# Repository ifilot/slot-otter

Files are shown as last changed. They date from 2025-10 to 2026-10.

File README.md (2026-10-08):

# Slot-otter





An 8-bit ISA card for accessing FAT16- or FAT32-formatted SD cards under MS-DOS.

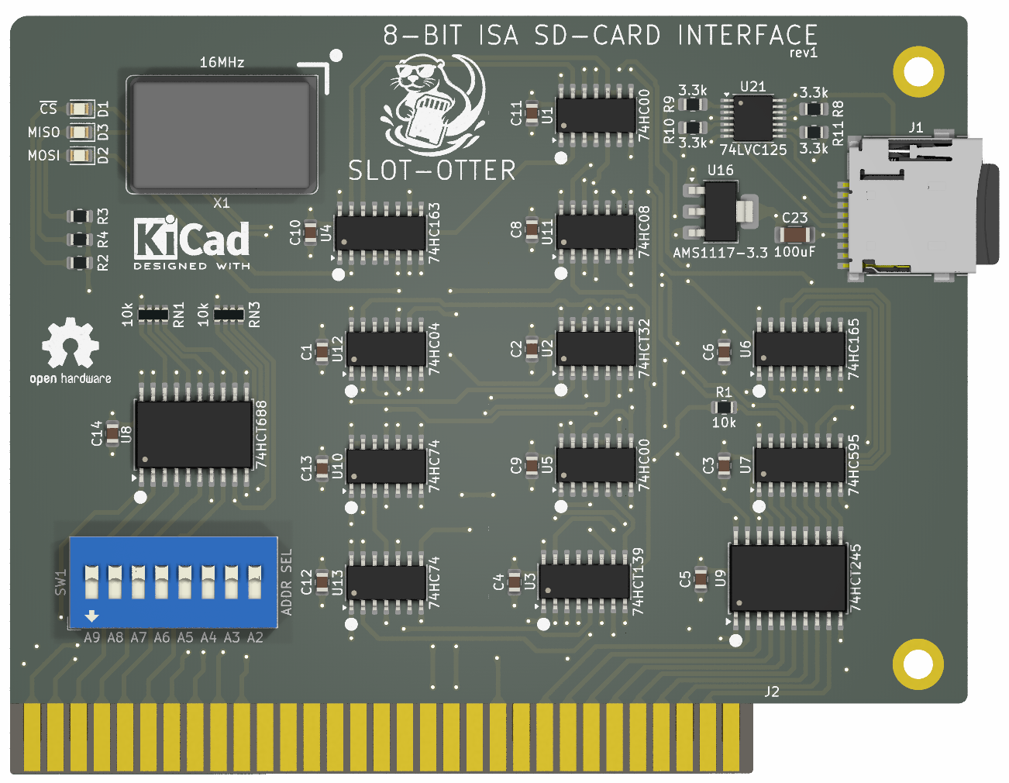
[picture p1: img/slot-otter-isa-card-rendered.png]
Slot-otter ISA card rendered


Slot-otter lets a DOS PC use an SD card as an ordinary drive. Fill the card
with files on a modern computer, insert it into your vintage PC, and copy or
run them from DOS. A working setup has three parts:

- the **Slot-otter card** in a free 8-bit ISA slot;
- the **OTTERSD driver** on the PC's hard drive, loaded at startup;
- an **SD card** with a FAT16 or FAT32 file system.

New users should read [How it works](#how-it-works) and
[Requirements](#requirements), then follow [Getting started](#getting-started)
step by step.

## Contents

- [How it works](#how-it-works)
- [Requirements](#requirements)
- [Getting started](#getting-started)
  - [1. Set the port address](#1-set-the-port-address)
  - [2. Download the driver](#2-download-the-driver)
  - [3. Prepare an SD card](#3-prepare-an-sd-card)
  - [4. Install and load OTTERSD](#4-install-and-load-ottersd)
- [Using the card](#using-the-card)
  - [Changing or removing the SD card](#changing-or-removing-the-sd-card)
  - [Freeing memory for games](#freeing-memory-for-games)
  - [Write checks and read-only mode](#write-checks-and-read-only-mode)
  - [Browsing files with Nightwatch](#browsing-files-with-nightwatch)
- [Performance](#performance)
- [Hardware](#hardware)
- [Legacy Navigator](#legacy-navigator)
- [Development](#development)
- [License](#license)

## How it works

`OTTERSD` is the DOS driver for Slot-otter. It is usually started from
`AUTOEXEC.BAT`. It talks to the card over the ISA bus, reads the FAT16 or FAT32
file system on the SD card, and gives the card an ordinary drive letter such
as `S:`. From then on, DIR, COPY, XCOPY, games and other DOS programs use the
card like any other drive and never need to know it is an SD card.

A driver is needed because, on its own, MS-DOS can only use the storage the
PC's BIOS already supports, which means floppy drives and hard disks. Any
other storage device needs a small program that stays in memory and turns DOS
requests such as "open this file" or "list this directory" into commands the
hardware understands. CD-ROM drives are the familiar example. Before a `D:`
drive appears, `CONFIG.SYS` has to load the manufacturer's CD-ROM driver and
`AUTOEXEC.BAT` has to run `MSCDEX`. `OTTERSD` does both of those jobs in a single
program.

## Requirements

Check these before you start. The driver refuses cards or file systems it
cannot handle safely.

- **PC:** an 8088/8086 or later processor and a free 8-bit ISA slot.
- **DOS:** MS-DOS or PC-DOS 3.1 through 6.x.
- **Memory:** about 42 KiB of conventional memory while the driver is loaded.
  No EMS or XMS is needed.
- **SD card:** SDHC or SDXC, at least 501 MiB. Older SDSC cards (2 GB and
  smaller) are not supported.
- **File system:** FAT16 or FAT32 with standard 512-byte sectors on an MBR
  partition. FAT12, exFAT, GPT and extended partitions are not supported.
- **File names:** the usual DOS limit of eight characters for the name and
  three for the extension, such as `DUNE2.EXE`.

## Getting started

Setting up Slot-otter for the first time takes four steps. The first is done
on the card before it goes into the PC, the third on a modern computer, and
the rest under DOS.

1. Set the card's port address and install it in the PC.
2. Download the driver and copy it to the DOS hard drive.
3. Write an empty FAT16 or FAT32 image to an SD card and add your files.
4. Install and load OTTERSD.

### 1. Set the port address

The PC talks to expansion cards through I/O ports, small numbered addresses
that each card listens on. Slot-otter occupies four consecutive ports. The
driver needs to know where they start, and no other card in the PC may use
the same ones.

The base address is set with the 8-position DIP switch labelled **ADDR SEL**
(SW1). Each switch stands for one value. Switches that are ON add their
values together to give the base address; switches that are OFF add nothing.

| Switch | 1 | 2 | 3 | 4 | 5 | 6 | 7 | 8 |
| --- | --- | --- | --- | --- | --- | --- | --- | --- |
| Value (hex) | 200 | 100 | 80 | 40 | 20 | 10 | 8 | 4 |
| **330h** (default) | ON | ON | OFF | OFF | ON | ON | OFF | OFF |
| **300h** | ON | ON | OFF | OFF | OFF | OFF | OFF | OFF |

For example, 330h = 200h + 100h + 20h + 10h, so switches 1, 2, 5 and 6 are ON.
The examples in this README and the driver documentation use 330h. Choose any
free address from 100h to 3FCh. Sound cards often use 330h for their MIDI
port, so pick another address, such as 300h, if your PC has one. Whatever you
choose, pass the same value to the driver with `/PORT:` in
[step 4](#4-install-and-load-ottersd).

With the PC switched off, insert the card into a free 8-bit ISA slot.

### 2. Download the driver

The driver is distributed as a ZIP for copying with a modern PC, as a bare
executable, and as floppy images for PCs that only have a floppy drive. Get
the [latest release](https://github.com/ifilot/slot-otter/releases/latest):

- [OTTERSD-DOS.zip](https://github.com/ifilot/slot-otter/releases/latest/download/OTTERSD-DOS.zip): driver, instructions and license.
- [OTTERSD.EXE](https://github.com/ifilot/slot-otter/releases/latest/download/OTTERSD.EXE): driver executable.
- [floppy_360k.img](https://github.com/ifilot/slot-otter/releases/latest/download/floppy_360k.img): 360 KiB, 5.25-inch DD.
- [floppy_720k.img](https://github.com/ifilot/slot-otter/releases/latest/download/floppy_720k.img): 720 KiB, 3.5-inch DD.
- [floppy_1440k.img](https://github.com/ifilot/slot-otter/releases/latest/download/floppy_1440k.img): 1.44 MiB, 3.5-inch HD.
- [SHA256.TXT](https://github.com/ifilot/slot-otter/releases/latest/download/SHA256.TXT): checksums for checking that downloads are intact.

Floppies contain only the driver, user instructions, configuration example
and license. They contain no testing utilities and are not boot disks.
Write them to physical floppies or use GoTek,
[BitstreamBeaver](https://github.com/ifilot/bitstream-beaver) or FlashFloppy.

### 3. Prepare an SD card

The easiest way to get a card in the right format is to write one of the
ready-made images to it on a modern PC. Both images contain an **empty,
formatted partition** with no files or folders. After writing one, copy your
files onto the card with the same PC.

**Recommended: [500 MiB FAT16, 16 KiB clusters](https://github.com/ifilot/slot-otter/releases/latest/download/OTTERSD-FAT16-500MiB.zip).**
This gives a useful balance of storage space and write speed. A cluster is
the unit of space the card assigns to a file. Larger clusters mean less
bookkeeping when growing a file, although small files take up more space.

An alternative [500 MiB FAT32 image with 4 KiB clusters](https://github.com/ifilot/slot-otter/releases/latest/download/OTTERSD-FAT32-500MiB.zip)
is also available.

Extract the ZIP and write its IMG to the **entire card**. This replaces existing
partitions and files: back up first and select the correct device. Do not copy
the IMG as a file or reformat the card afterwards. The image occupies 501 MiB,
including a small area before the 500 MiB partition. On a larger card, the
remaining space is unused by this image. These images hold your files; they
do not boot DOS.

A card that is already formatted FAT16 or FAT32 and meets the
[requirements](#requirements) can also be used without writing an image.

### 4. Install and load OTTERSD

The driver is copied to the hard drive and started like any other DOS program.
It must not be loaded from the SD drive it provides.

Copy OTTERSD.EXE to a directory on your DOS hard drive, such as `C:\OTTERSD`.
Choose an unused drive letter; this example uses `S:`. Add `LASTDRIVE=S` to
CONFIG.SYS (or keep an existing value of S or later), then reboot, insert the
SD card and load:

```dos
C:\OTTERSD\OTTERSD /DRIVE:S /PORT:330 /RW
```

`/PORT:330` must match the DIP-switch setting from
[step 1](#1-set-the-port-address). `/RW` enables writing with read-back checks.
Omit it or use `/RO` for read-only access. Once the driver reports that the
card is mounted, you can use commands such as `DIR S:\`.

Add the loading command to AUTOEXEC.BAT if you want it to run at startup.
Run OTTERSD as a program; do not add it as a `DEVICE=` line in CONFIG.SYS.
See the [installation guide](driver/docs/INSTALLATION.md) for the full setup
and available options.

## Using the card

Once loaded, the SD drive behaves like any other DOS drive. A few things
differ from a fixed hard disk, mainly because the card can be removed and the
driver can be unloaded.

### Changing or removing the SD card

**Always unmount before removing a card, and mount again after inserting one.**
Treat this like safely ejecting a card on your modern PC. DOS programs and
the driver can keep file data and information about the card in memory.
Removing or swapping a mounted card can lose changes or cause the driver
to use information belonging to the previous card, risking file corruption.

1. Finish copying and close any programs using the SD card. Return to a
   drive other than the SD card, such as `C:`.
2. Run `C:\OTTERSD\OTTERSD /UNMOUNT`. **Wait for it to succeed before
   removing the card.** If it reports an error, leave the card inserted
   and resolve the error first.
3. Remove the card and insert the card you want to use.
4. Run `C:\OTTERSD\OTTERSD /MOUNT` and wait for it to succeed before
   accessing the SD drive again.

Follow these steps even when reinserting the same card, especially after
changing its contents on another computer. Unmounting leaves the driver
loaded, so you do not need to reboot to change cards.

### Freeing memory for games

Some games need every kilobyte of conventional memory. The driver can be
removed from memory without rebooting: close programs using the SD card,
switch to your hard drive and run `C:\OTTERSD\OTTERSD /UNLOAD`. Run the
loading command again to bring the SD drive back.

### Write checks and read-only mode

With `/RW`, every block written to the card is read back and checked before
the write is reported as successful. With `/RO`, or without either option,
the card is mounted read-only and nothing on it can be changed. The access
mode is fixed when the driver is loaded; reboot to change it.

### Browsing files with Nightwatch

For browsing and copying files, we recommend
[Nightwatch](https://github.com/ifilot/nightwatch) together with OTTERSD.
Nightwatch is a separate project and is not bundled in these downloads.

## Performance

File-copy tests on an **80286 running at 20 MHz** gave these results:

| Direction | FAT16 card | FAT32 card |
| --- | --- | --- |
| To the SD card | 15 KiB/s | 10 KiB/s |
| From the SD card | 38 KiB/s | 38 KiB/s |

These are measured file-transfer speeds, not guaranteed speeds for every
system or card. FAT16 was faster when writing in these tests; reading was
equally fast with both formats. Speeds also depend on the CPU, the ISA bus
and the disk being copied to or from.

## Hardware

The KiCad design files for the card are in [pcb/release](pcb/release),
including the schematic as a [PDF](pcb/release/isa-sdcard.pdf) and the BOM
and placement files for assembly. The card is built from standard 74-series
logic. A 74HCT688 compares address lines A2 to A9 with the DIP-switch setting
described in [Set the port address](#1-set-the-port-address).

## Legacy Navigator

OTTERNAV remains available for users of the older software. It accesses the
card directly, without loading OTTERSD. Its source is under [src](src/README.MD), with a separate
[OTTERNAV.EXE download](https://github.com/ifilot/slot-otter/releases/latest/download/OTTERNAV.EXE).
It is not included on the OTTERSD floppies. Unmount OTTERSD before using Navigator
on the same card.

## Development

Standalone driver source, build scripts and regression tests live under
[driver](driver/README.md), together with the technical documentation.
Turbo C 2.0 and TASM 2 build the binaries.
[DOSBox-VirtIsa](https://github.com/ifilot/dosbox-virtisa) models the ISA interface;
real DOS kernels and hardware provide additional validation. Developer hardware
kits and test images are separate from public downloads. Disk images,
release packages and build outputs are generated by the tools and GitHub
Actions; they are not stored in the source repository.

## License

Slot-otter is released under the
[GNU General Public License v3.0](https://www.gnu.org/licenses/gpl-3.0).

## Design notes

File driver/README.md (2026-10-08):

# OTTERSD driver

This directory contains the source, build scripts and tests for `OTTERSD.EXE`,
the DOS driver for the Slot-otter card, and `HWRT.EXE`, its developer
hardware tester. It is self-contained: nothing here depends on the
legacy Navigator in `../src`.

This document is for developers. End users should follow the
[installation guide](docs/INSTALLATION.md), which is also shipped as
`README.TXT` in the public downloads.

## Contents

- [Overview](#overview)
- [Command-line reference](#command-line-reference)
- [Platform and scope](#platform-and-scope)
- [Design](#design)
- [Source layout](#source-layout)
- [Building and testing](#building-and-testing)
- [Releasing](#releasing)

## Overview

OTTERSD is a TSR filesystem redirector. It hooks the DOS network-redirector
interface (INT 2Fh), so it is started as an ordinary program, for example from
AUTOEXEC.BAT, rather than loaded with `DEVICE=` in CONFIG.SYS. Once installed,
it reads the FAT16 or FAT32 volume on the SD card and serves DOS file requests
for the chosen drive letter. A single executable handles both file systems,
read-only and verified read/write access.

CONFIG.SYS needs a LASTDRIVE at or beyond the chosen letter. The tested
configuration is:

```dos
LASTDRIVE=S
FILES=40
BUFFERS=10
```

## Command-line reference

Install from a local disk, never from the SD drive itself:

```dos
OTTERSD /DRIVE:S /PORT:330 /RW
```

| Option | Meaning |
| --- | --- |
| `/DRIVE:x` | Drive letter to provide (C to Z). Required at installation. |
| `/PORT:hhh` | Card base port in hexadecimal, matching the DIP switch. Default 330. |
| `/RO` | Read-only access. This is the default. |
| `/RW` | Read/write access with read-back verification of every sector. |
| `/NOVERIFY` | With `/RW`: skip the read-back. See [Write verification](#write-verification). |
| `/SKIPFATCHECK` | With `/RW`: faster mount. See [Mounting](#mounting). |
| `/FAT16`, `/FAT32` | Accept only that file system. Without either, it is detected automatically. |

The access mode and options are fixed at installation; reboot or `/UNLOAD`
to change them. A second installation is rejected. If no usable card is
present, the driver stays loaded with the drive offline.

Control commands operate on the installed driver:

| Command | Effect |
| --- | --- |
| `OTTERSD /STATUS` | Report version, mode, policies and the last SD diagnostic. |
| `OTTERSD /UNMOUNT` | Commit and check the FAT copies, mark the volume clean and take the drive offline. Required before removing the card, rebooting or using Navigator. |
| `OTTERSD /MOUNT` | Bring the drive online again after inserting a card. |
| `OTTERSD /UNLOAD` | Remove the driver completely and free its memory. |

`/UNMOUNT` and `/UNLOAD` refuse to run while files on the SD drive are open.
`/UNLOAD` must also be run from another drive, and it refuses if a TSR loaded
later has hooked INT 2Fh after OTTERSD, if DOS memory ownership is not as
expected, or if a commit fails. A failed mount or transport operation leaves
the drive offline with the TSR still loaded. Handles and searches opened
before that point cannot resume against a different card.

## Platform and scope

- **CPU:** 8088/8086 or later. No 286 instructions, EMS, XMS, DMA or IRQ line are used.
- **DOS:** MS/PC-DOS 3.1 through 6.x. DOS 5 and 6.22 with 1 MiB of emulated RAM
  are the qualification kernels. DOS 3/4 and a physical 5150/8088 are not yet
  tested; a 286 with 1 MiB is the current hardware target.
- **Media:** SDHC/SDXC with 512-byte sectors; FAT16 or FAT32 in the first
  primary MBR partition, or as a superfloppy.
- **Memory:** 42,896 bytes of conventional memory including the PSP, in either
  access mode. Validation and packaging fail above 45,000 bytes. Resources include a
  2,048-byte private stack, 16 open-file slots and 32 search cursors. DOS
  FILES and process limits also apply.

File names are DOS 8.3 names or the 8.3 aliases of existing long names.
Supported operations include creating, overwriting, appending, truncating
and extending files; deleting files; attributes and timestamps; creating and
removing directories; and moving across directories. Handle sharing,
duplicate handles and region locks are implemented. Standard FCB wildcard
deletion is tested; FCB record I/O and abort handling are not.

Not supported: GPT, extended partitions, SDSC cards, FAT12, exFAT, creating
long file names, and general DOS network-server functions.

## Design

### Write verification

By default, every 512-byte sector written goes through these checks: a CRC,
the card's accepted response, bounded busy and status waits, a CRC-checked
read-back, and an exact comparison with the intended data. The intended data
is held in a frozen copy for the duration of the write. A failed sector is
tried at most three times in total, and only after the card's identity and
usable reads have been re-established. If the failure cannot be resolved, the
session is poisoned and no further writes are accepted.

`/NOVERIFY` drops only the read-back and comparison. CRC, response, busy,
CMD13 status, identity and recovery checks remain. It can therefore
acknowledge data the card stored incorrectly, and must be chosen explicitly
at installation. The installer, `/STATUS` and HWRT report the active policy.
The diagnostic `verified` counter counts completed sector writes in both modes.

Writes are synchronous; there is no write-back cache. Verified sector writes
do not make multi-sector FAT updates transactional. Closing a file finishes
its data and directory writes but leaves the volume marked dirty, to avoid
comparing both complete FATs on every close. An explicit DOS commit, a global
flush and `/UNMOUNT` compare the FAT copies before marking the volume clean.
A volume left dirty by an interrupted session is refused at the next mount and
needs checking on another computer; the driver never clears the flag silently.

### Mounting

A full mount checks the geometry, capacity, backup boot sector, FAT flags,
FSInfo signatures and that all FAT copies match. It does not scan for
allocation errors or cross-linked files.

`/SKIPFATCHECK` skips the complete FAT comparison at mount and compares only
the first FAT sector. All other mount checks, the comparisons made before FAT
changes and the full commit checks remain. It requires `/RW`; `/RO` never
performs the full comparison.

### Caching and card changes

Reads use separate caches: one payload sector, four FAT sectors and two
directory sectors. Under `/RW`, each open handle also keeps its position in
the cluster chain, so sequential reads need not walk the chain from the start.
Every cached FAT access, including a cache hit, rechecks the card's identity.
Before any write, all retained positions are invalidated and any cached copy
of the sector being written is discarded. A write starts its own validation
from freshly read data rather than from cached results. Removing or replacing
the card invalidates the mounted file system. Cards must be unmounted before
raw-sector tools or Navigator change them.

### Allocation

Newly allocated clusters for regular files receive the incoming data directly,
without being zeroed first. File reads stop at the end of the file, so stale
bytes beyond it are never visible. Gaps and explicit extensions are filled
with zeros, and new directory clusters are cleared before they are linked.

### Disk-space reporting

The DOS free-space call uses 16-bit counts. To report large volumes, the
driver presents larger logical allocation units than the physical clusters,
up to 32 KiB, and rounds total and free counts down. The physical geometry is
unchanged. Volumes above about 2 GiB still exceed what the call can report.

## Source layout

| File | Responsibility |
| --- | --- |
| INSTALL.C / INSTALL.H | Installation and control commands; discarded after loading |
| BOOT.C / CRT.C | Retained bootstrap and CRT/far call gates |
| ENTRY.ASM | 8086 interrupt bridge, private stack and resident boundary |
| REDIR.C / RWOPS.C / RWDIR.C | DOS redirector, handles, locks and write callbacks |
| FAT32.C / RWFS.C / RWFS.H | FAT16/FAT32 reading, writing and directory operations |
| SDRW.C / RWSD.H | Card identity, recovery and verified sector transport; version number |
| FASTIO.ASM | 8086 far memory copy |
| PORTBODY.H | Shared, exhaustively tested option parser |
| HWRT.C / TESTCHLD.C | Hardware tester, including its self-exec child mode |
| installer_segments.py / tests/layout.py | Checks that installer segments are discarded and the startup reserve fits |

| Directory | Contents |
| --- | --- |
| `docs/` | [Installation guide](docs/INSTALLATION.md), [hardware test manual](docs/MANUAL.md), developer image notes ([FAT16](docs/FAT16_IMAGE.md), [FAT32](docs/LARGE_IMAGE.md)), [source conventions](docs/CODING.md) and [DOS ABI notes](docs/DOSREF.md) |
| `tests/` | Host, mutation, native DOS and XCOPY tests; see [tests/README.md](tests/README.md). `tests/reference/` holds earlier protocol code used only as test input; `tests/emulation/` holds the SD card model and emulator adapters. |
| `logs/` | Physical-card logs: `logs/historical/` for earlier runs, `logs/<card-name>/` for new ones |
| `dist/` | Generated build, kit and release output. Ignored by Git. |

## Building and testing

### Requirements

Turbo C 2.0 and TASM 2 are supplied separately, in `../buildenv` or the
directory named by `TOOLCHAIN_DIR`. `DOSBOX_BIN` selects the DOSBox used to
run the compiler. Python 3, GCC/gcov, mtools and dosfstools are needed for the
host tests and packaging.

### Build and validate

```sh
bash driver/build.sh /tmp/otter-build
python3 driver/validate.py --output /tmp/otter-check
python3 driver/validate.py --full --output driver/dist \
  --dosbox /path/to/dosbox-with-isa-model \
  --boot-image /path/to/dos5.img --boot-image /path/to/dos622.img
```

`build.sh` builds both programs. `validate.py` runs the host regression,
coverage and mutation tests, builds both programs and creates a candidate
developer kit.

`--full` also boots real DOS in an emulator with the
[DOSBox-VirtIsa](https://github.com/ifilot/dosbox-virtisa) ISA model. It runs:
- read-only, command-line, EXEC and card-swap tests;
- write-fault profiles and tester guards;
- XCOPY from a BIOS hard disk at two cluster sizes and with each write policy;
- stress, memory and reboot tests on the final image, with independent
  content comparison and fsck.

These tests need `XCOPY.EX_` in each boot image and `EXPAND.EXE` in one of
them, or in `--xcopy-expand-media`. Boot images, compiler images, XCOPY and
the emulator are not redistributed. Results, gate logs and
`EVIDENCE/QUALIFICATION.JSON` are written to the output directory.

Emulation does not qualify physical hardware.

### Testing on a real card

Validation produces developer kits with HWRT and test fixtures:
`dist/OTTERSD.IMG` (small FAT32 stress image) with `dist/OTTERSD.ZIP`, plus
500 MiB images in `dist/FAT16/` and `dist/500M/`. Follow the
[hardware test manual](docs/MANUAL.md) separately for each card. HWRT records
the card's CID, capacity, versions, source identifier, timings and
diagnostics. Save each card's logs under `logs/<card-name>/`. Results from an
earlier build do not carry over to a new one.

## Releasing

`release.py` builds the public downloads from a qualified `OTTERSD.EXE`:

```sh
python3 driver/release.py --driver /path/to/OTTERSD.EXE \
  --output /path/to/new-public-output
```

It produces:
- the DOS ZIP;
- 360 KiB, 720 KiB and 1.44 MiB installation floppies;
- empty 500 MiB FAT16 and FAT32 SD images, with FAT16 at 16 KiB clusters recommended;
- `SHA256.TXT`.

The ZIP and floppies contain only `OTTERSD.EXE`, `README.TXT` (from
[INSTALLATION.md](docs/INSTALLATION.md)), a CONFIG.SYS example and the
license. They include no HWRT, fixtures or test markers. The script never uses
the developer fixture builders. It refuses an existing output directory and
checks each floppy's file list, the SD geometry, FAT copies, root contents,
backup boot sector, FSInfo and fsck results. Local output can be placed in
`dist/RELEASE/`.

GitHub Actions runs the host and mutation tests, builds the binaries and
uploads only `release.py`'s output. A tagged release requires the tag to be
`v` followed by the version in RWSD.H. OTTERNAV is built separately and
attached as an optional legacy download.

RWSD.H defines the displayed version and a 16-bit resident version ID: the
major version in the high byte, and minor and patch in the two low nibbles.
HWRT refuses to work with a driver of a different version.

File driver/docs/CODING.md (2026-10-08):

# Resident source conventions

The DOS sources target Turbo C 2.0's C89 subset and TASM's `.8086` instruction
set. Keep declarations at block starts, use `/* ... */` comments in C and `;`
comments in assembly, and retain explicit `far` pointers at DOS memory and
transfer boundaries. Modern Python and the host card model are test tools;
they need not imitate a 1980s compiler.

Use the existing U8/U16/U32 types when width is part of a disk format or DOS
ABI. DOS `int` is 16 bits. A far pointer's offset is also 16 bits; ordinary
pointer addition is insufficient for a transfer crossing offset FFFFh.
Keep unsigned arithmetic explicit where overflow, sector bounds or time
counter wrap is intentional.

Comments should explain contracts, ownership, ordering and unusual constraints.
Document which error survives a failure and which state is invalidated. Avoid
restating obvious assignments or turning measured evidence into a guarantee.
DOSREF.md records DOS structure offsets and the private diagnostic interface;
RWSD.H and RWFS.H describe the transport and filesystem contracts.

Resident callbacks must not call DOS, allocate memory, or print diagnostics.
The interrupt bridge provides a static stack and prevents nested use of shared
scratch. Installation code may use DOS before becoming resident. The linker
boundary includes all resident code/data and the private stack, and releases
the startup stack/heap and explicit far installer tail after installation.
BOOT gates are the only external far targets permitted in installer assembly;
local far frames must also be verified before linking. PORTBODY.H shares the
parser implementation between retained test utilities and the far installer.

Verified sector writes do not make FAT operations atomic. Mount preflight is
not a complete consistency scan. Any claim about recovery, memory use, or a
DOS API must distinguish host tests, actual booted DOS and physical hardware.

For a comments-only pass, retain a pre-edit build and compare rebuilt EXE files
byte for byte. Run the regression suite as well. Formatting changes are kept
small so an invariant explanation remains easy to review separately from a
behavior change.

FASTIO.ASM uses a near small-model C call for normalized far memory copying.
Its source and destination must be normalized before each <=512-byte chunk;
neither offset may wrap. The helper preserves BX/SI/DI/BP/DS/ES, clears DF and
leaves interrupts enabled. Native tests check odd tails, source preservation,
segments and register contracts with deliberately broken assembly variants.

The SD transport in SDRW.C is the complete 0.6 C implementation restored after
a physical regression in 0.7. Its OUT plus settling/sample reads must not be
compressed into assembly without an elapsed-time contract and physical proof.
An emulator that counts accesses cannot establish electrical settling time.
The C CRC is tested against independent host and native bitwise oracles.

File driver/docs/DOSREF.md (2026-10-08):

# Writable redirector ABI references

The original [Ralf Brown Interrupt List, release 61](https://www.cs.cmu.edu/~ralf/files.html)
is the authority for the undocumented DOS interfaces used here (INTERRUP.K,
tables 02606, 01687, 01690, 01641/01642/01643). Do not substitute DOSBox's
built-in DOS behavior for actual kernel validation.

- DOS 3 locks pass position in CX:DX and length in SI plus a stack word.
  DOS 4–6 use BL to distinguish lock/unlock and DS:DX to an eight-byte
  position/length record; CX is one. Unlock must match the original range.
- Create uses stack attributes and a create-new flag. Extended open instead
  uses the SDA action, mode, and attributes; DOS 5/6 have documented stack
  attribute and returned-action bugs. Callback action results remain correct.
- Rename's second canonical pathname is 128 bytes after the first pathname
  buffer. These buffers have different sizes from this driver's path limit.
- DOS owns SFT reference counts on open; the redirector decrements them on
  close. Commit flushes without decrementing them.
- File time updates arrive through the SFT. File creation dates use the SDA
  date and time derives from the BIOS tick count without reentering DOS.
- Ordinary DOS UNLINK rejects wildcards before reaching the redirector.
  FCB deletion (INT 21h/AH=13h) and COMMAND.COM DEL pass under booted DOS 5
  and 6.22, including a directory grown across cluster boundaries. The optional
  `/SERVER` probe using canonicalized INT 21h/AX=5D00h still returns error 3
  without a new redirector error; that experiment is not a validated path.

SFT offsets used for DOS 3.1-6.x (byte offsets, little endian):

| Offset | Field | Ownership |
|---|---|---|
| 0 | reference count, WORD | DOS initializes; redirector decrements on close |
| 2 | open mode, WORD | redirector stores validated DOS mode |
| 4 | attributes, BYTE | refreshed from directory metadata |
| 5 | device/network flags, WORD | remote drive and inheritance flags |
| 7 | device/DPB or redirector pointer, DWORD | unused here; initialized to zero |
| 11 | starting cluster, WORD | unused for remote FAT32; full cluster lives in driver state |
| 13, 15 | FAT time/date, WORDs | preserve pending DOS handle-time updates |
| 17 | file size, DWORD | synchronize all open SFTs when size changes |
| 21 | file position, DWORD | individual SFT position; duplicates share it |
| 25-31 | cluster/position fields | initialized; traversal lives in driver state |
| 32-42 | short filename | eleven-byte padded alias |
| 43 onward | sharing/process linkage | preserve DOS-owned fields on open |

The writable build's private INT 2Fh/AX=D74Fh query is for the test program and
installer. Discovery without the control signature returns AX=4F54h,
BX=524Fh, CX=zero-based drive, DX=online, SI=open SFT slots, DI=ISA base port.
BP=3 identifies the enhanced build; BP=2 is the older read-only build.
Discovery checks media presence and can take the driver offline.

Controls require BX=4F54h and DX=524Fh. CF indicates failure with a DOS error
in AX; otherwise AX is zero except for selectors with explicit AX results:

| SI | Operation | Successful results |
|---|---|---|
| 1 | unmount after flushing | fails while any resident file slot is open |
| 2 | initialize and remount in installed mode | also requires zero file slots |
| 4 | copy transport diagnostics | ES:DI writable buffer, CX at least 40; CX=40 |
| 5 | installed mode | BX=write enabled, CX=3 total sector attempts, DX=online, DI=post-write readback enabled |
| 6 | last callback failure | AX=11xx function, BX=DOS error before kernel mapping |
| 7 | observed private stack use | AX=used, BX=untouched prefix, CX=2048 |

Selector 4 rejects a buffer crossing the 16-bit offset boundary. Its fixed
40-byte layout and stage/counter meanings are in RWSD.H. Unmount preserves
transport diagnostics; remount clears them even when its initialization fails.
The last callback failure is sticky, so it can describe an earlier operation.
Stack scanning measures observed use of the A5 pattern, including IRQs during
callbacks; it does not prove the maximum possible stack demand.

Process/FCB termination callbacks 111Dh and 1122h currently chain. RBIL describes
the sharing PSP at SDA 1Ah (DOS 3) or 1Ch (DOS 4-6), distinct from the current
PSP at 10h. Normal DOS process exit is tested with seventeen child runs leaving
six handle-based files and one region lock unclosed. DOS close callbacks release
all resident slots and locks. Abnormal abort and FCB record-I/O handle lifetime
remain unqualified; do not infer them from the normal-exit result.

See the specific [write callback](https://fd.lod.bz/rbil/interrup/network/2f1109.html),
[rename callback](https://fd.lod.bz/rbil/interrup/network/2f1111.html), and
[extended open callback](https://fd.lod.bz/rbil/interrup/network/2f112e.html).

## Consolidated identity query (action 8)

The private D74Fh/OT/RO multiplex control uses SI=8, CX >=32 and ES:DI pointing
to a 32-byte DriverInfo. Far offsets at FFE0h and above are rejected. CF clear returns
CX=32. Fields are last LBA (U32), CID (16 bytes), version (U16,000Bh), resident
bytes, SD ticks, filesystem ticks, flags and ABI (U16,1). Flags: bit0 cached
identity valid, bit1 installed writable mode, bit2 online, bit3 post-write readback disabled. CID is zero when
invalid; capacity is meaningful only with valid identity. This cached query
performs no SD I/O and does not freshly authenticate a removed card.
Mount tick fields are U16 BIOS low-word deltas for short operations; midnight
reset or unusually long mounts can distort them. The older 40-byte action4
diagnostic layout is unchanged.

The action4 `verified` counter retains its completed-sector-call ABI meaning.
With flag bit3 set it does not certify sector readback. /NOVERIFY is fixed at
installation and does not disable command/data CRC or recovery reads.

## DOS disk-space geometry

[INT 2F/110Ch](https://fd.lod.bz/rbil/interrup/network/2f110c.html) returns
AL sectors per allocation unit, AH media ID, BX total units, CX bytes per
sector and DX available units. Total/free counts are only 16 bits. Version
0.9 doubles the reported allocation unit and halves both counts until the
total fits, keeping synthesized units at most 32 KiB. Counts round down, so
the result loses less than one logical unit when the volume is representable.
The FAT32 BPB, physical cluster size and allocator do not change. A 500 MiB
volume with 4 KiB physical clusters is reported using 8 KiB logical units.
Read-only mode reports total capacity but zero writable free units. The
legacy interface still saturates above approximately 2 GiB at that unit-size
ceiling; this is not an extended FAT32 disk-space API. Pre-existing 64 KiB
physical clusters retain their previous unit size rather than wrapping AL.

### Unload ABI (OTTERSD 0.10)

Private INT 2F AX=D74Fh, BX=4F54h, DX=524Fh, SI=9 returns CF clear,
AX=resident PSP, BX:CX=own vector offset:segment, DX:DI=previous vector
offset:segment, SI=000Ah. This query does not flush or mutate the drive.
SI=10 prepares detachment: verify the topmost INT 2F vector, reject open files
or a poisoned/lost dirty session, flush writable online media, take it offline, restore
all 51h (DOS 3) or 58h (DOS 4+) saved CDS bytes. CF/AX reports failure; commit
failure leaves the CDS and hook installed. The transient caller must verify
the current drive and DOS MCB ownership before SI=10, then restore the saved
vector and free the PSP allocation with INT 21/AH=49 only after returning.
Never call DOS or free the allocation on the resident interrupt stack. No
third-party hook may be bypassed. These operations are version-matched and
intended for the shipped /UNLOAD command, not a generic TSR chain editor.

### Fast-mount policy in 0.11

DriverInfo ABI 1 remains 32 bytes. Flags bit 4 (0010h) records the installed
/SKIPFATCHECK policy; other flag meanings are unchanged. Private unload query
SI=9 returns version SI=000Bh for this release. /SKIPFATCHECK skips only the
full mount scan. FAT sector zero is compared at mount and before clean/dirty
flag publication, modified FAT sectors remain compared, and rw_flush still
compares all mirrors for a dirty session. No policy control changes an already
resident instance. Read-only mounting does not perform the full scan.

### Dual-format status flags (OTTERSD 0.13)

DriverInfo ABI 1 remains 32 bytes. Flags 0020h identify a mounted FAT16 volume;
with mounted flag 0004h set and 0020h clear, the volume is FAT32. Offline volumes
have no reported type. Flags 0040h and 0080h record `/FAT16` and `/FAT32`
restrictions respectively; both clear means automatic detection. Restrictions
persist across unmounts, removals, and explicit remounts. No on-disk format
conversion occurs. The internal ROOT16 sentinel is FFFFFFFFh and never a data
cluster. FAT16 reserved/EOF entries normalize into the existing internal FAT32
marker range; writes serialize only the original two-byte FAT16 entries.

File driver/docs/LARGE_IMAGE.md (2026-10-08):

# Developer 500 MiB FAT32 SD image

For the empty END-USER image, use `dist/RELEASE/OTTERSD-FAT32-500MiB.zip`
and [INSTALLATION.md](INSTALLATION.md). The fixture below is for developers
and is not included in the public release.

OTTER500.IMG contains one 500 MiB FAT32 partition at a 1 MiB offset in an MBR
disk image. The entire image is 501 MiB. It uses 512-byte sectors, 4 KiB
clusters (eight sectors), two FAT copies, FSInfo and a backup boot sector.
The data area begins at 2 MiB, so both the partition and data are 1 MiB aligned.
It is a data disk, not a bootable DOS disk. Extra capacity on a larger card
remains outside this partition.

The previous small image intentionally used 512-byte clusters to exercise
allocation heavily. A 400 KiB file needs 100 clusters with this image instead
of 800. This reduces FAT allocation and chain traversal work. Sector writes
still transfer 512 bytes, with CRC and default readback verification. Larger
clusters do not remove that cost. Small files can waste up to 4095 bytes each.
Mount and unmount compare complete FAT copies; their cost can increase with
this larger volume. Measure copying separately from mount/unmount.

Eight KiB clusters would put a 500 MiB volume below the FAT32 minimum of
65525 data clusters. Four KiB keeps this image unambiguously FAT32. Changing
the sector size is a different operation and is not supported by this driver.
OTTERSD 1.0.0 reports 8 KiB logical allocation units to DOS on this volume,
scaling total/free counts to fit the legacy 16-bit interface. The physical
clusters stay 4 KiB. DIR should report about 499 MiB free initially, allowing
for the FAT/reserved area and supplied files. Reported free space rounds down
by less than 8 KiB. Read-only mode reports zero writable free space.
The cluster-count rule is specified in Microsoft's FAT specification:
https://www.cs.fsu.edu/~cop4610t/assignments/project3/spec/fatspec.pdf (pages 14-15).

## First hardware run

1. Back up the spare card. Flash OTTER500.IMG to the entire card with your
   usual image-writing tool. This replaces the partition table and files.
   Do not copy the image as a file or reformat the partition afterwards.
2. Boot DOS with the driver absent. Use Navigator to copy every file in KIT
   to a local writable directory, such as C:\OTTERSD. Exit Navigator.
3. Ensure CONFIG.SYS contains LASTDRIVE=S, FILES=40 and BUFFERS=10. Reboot.
   Remove any automatic installation of an older driver for this test.
4. From the local kit directory, run:

```
OTTERSD /DRIVE:S /PORT:330 /RW > INSTALL.LOG
TYPE INSTALL.LOG
OTTERSD /STATUS > STATUS.LOG
HWRT /INFO /PORT:330
HWRT /TEST /ERASE /PORT:330
HWRT /STRESS /ERASE /PORT:330
HWRT /MEMORY /PORT:330
OTTERSD /UNMOUNT > UNMOUNT.LOG
```

Use the real ISA port if different. Start with default verified writes.
Reboot without re-imaging, install the same driver with /RW, then run
HWRT /VERIFY /PORT:330. Preserve all logs separately for each card. MANUAL.TXT
explains the tests, expected negative-test messages and failure diagnostics.

## Copy timing

After the test passes, choose a local source directory containing a known
400 KiB file. Create S:\COPY and time:

```
MD S:\COPY
XCOPY C:\SOURCE\*.* S:\COPY /S /E
OTTERSD /UNMOUNT
```

Record copying and unmount times separately. After reboot, compare every
copied byte against the source, preferably also on the modern PC. Record card,
DOS/CPU, source size, cluster size and driver mode with the logs. Use the same
files and card for comparisons with the small image. The image does not
promise a particular physical speedup; software emulation cannot measure
the real ISA/card timing.

## Rebuild and emulation

From the repository root, with Python 3, mtools and dosfstools installed:

```
python3 driver/image.py --output /tmp/otter500 --kit driver/dist/KIT
```

The builder keeps the supplied OTTERSD.EXE/HWRT.EXE unchanged. It includes
standalone driver sources, source/file hashes and filesystem-check evidence
in OTTER500.ZIP. --reuse-image adds evidence without changing an already
tested image. It refuses to replace an existing image by default.

To exercise the exact image with a separately supplied genuine DOS boot
disk, licensed XCOPY/EXPAND media and the ISA SD model emulator:

```
python3 driver/tests/hardware.py --dosbox MODEL_DOSBOX --boot-image DOS_BOOT \
  --driver KIT/OTTERSD.EXE --tester KIT/HWRT.EXE --image OTTER500.IMG
python3 driver/tests/xcopy.py --dosbox MODEL_DOSBOX --boot-image DOS_BOOT \
  --expand-media EXPAND_MEDIA --driver KIT/OTTERSD.EXE --spc 8 \
  --image OTTER500.IMG --mode verified
```

Both harnesses modify private copies. Passing them qualifies the emulated
filesystem/driver interaction, not physical hardware or Windows reformatting.

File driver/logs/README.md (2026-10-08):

# Physical card logs

Keep each NEW run in a separate folder, for example SanDisk-2026-10-07 or
Intenso-2026-10-07. Include the manual's logs plus card/model/CID, DOS/CPU/RAM
and executable hashes. Logs are evidence, not build inputs.
Original read-only, raw-write and resident-writer hardware logs are kept in
`historical/`. They are evidence for those earlier binaries; do not relabel
them as runs of the current executable. Generated release archives, disk
images and build outputs are not stored here.

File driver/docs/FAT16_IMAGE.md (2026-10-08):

# Developer 500 MiB FAT16 hardware-test image

For the empty END-USER image, use `dist/RELEASE/OTTERSD-FAT16-500MiB.zip`
and [INSTALLATION.md](INSTALLATION.md). The fixture below is for developers
and is not included in the public release.

`driver/dist/FAT16/OTTER16.IMG` contains a 500 MiB primary FAT16 partition
with 16 KiB clusters (32 sectors of 512 bytes each). The whole image is 501 MiB:
the partition begins at the 1 MiB boundary. This is a data card, not a DOS boot disk.

OTTERSD automatically detects FAT16 and FAT32. For this image use:

    OTTERSD /DRIVE:S /PORT:330 /RW /FAT16

`/FAT16` restricts mounting to FAT16; `/FAT32` restricts it to FAT32. Omit both
for automatic selection, including after a card swap. Neither option formats
or converts a card. Use the matching OTTERSD and HWRT files from this kit.

Follow the accompanying MANUAL.TXT for installation and the complete hardware
suite. Start with verified writes; `/NOVERIFY` deliberately weakens readback
protection. Save logs on the regular hard disk. Unmount before removing the
card or using Navigator. Re-image a disposable card before destructive tests.

This FAT16 volume has approximately 32,000 clusters, two roughly 63 KiB FATs,
and a fixed root directory with 512 entries. DOS reports its physical 16 KiB
allocation units directly. Subdirectories can grow; the root cannot grow. Long
Windows names consume additional root entries even though OTTERSD uses short
8.3 aliases. FAT16's larger clusters reduce FAT traffic for large files but
waste more space for small files. Sector transfers still use 512-byte blocks.

Windows can read this volume and copy files using its FAT support. Preserve
FAT16 if reformatting: FAT32 with 16 KiB clusters on 500 MiB has too few clusters
to be a valid FAT32 volume. The driver supports FAT16 volumes with 4,085 through
65,518 data clusters and rejects FAT12, GPT, and extended-partition layouts.
This image retains standard FAT16 geometry: one reserved sector, two FATs,
and 512 root entries. The data area is not separately padded to 1 MiB.

The original FAT32 images remain available and use the same dual-format
executables. The shipped test markers authorize writes only on disposable test
cards. Hardware results are required before claiming this new release is
qualified on a particular card or machine.

Reproduce emulation qualification after the main `validate.py --full` run:

    python3 driver/tests/large_kits.py --output /path/to/qualified-output \
      --dosbox /path/to/isa-model-dosbox \
      --boot-image /path/to/dos5.img --boot-image /path/to/dos622.img \
      --expand-media /path/to/licensed-expand-media.img --jobs 8

This builds both large formats and runs hardware-suite/persistence, unload,
verified and unverified XCOPY, read-only XCOPY, and DOS capacity checks on
private copies under both kernels. It bundles per-image evidence after success.

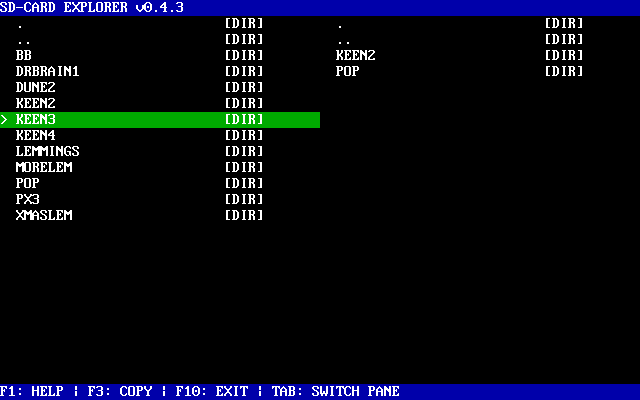
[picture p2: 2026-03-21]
img/screenshot.png

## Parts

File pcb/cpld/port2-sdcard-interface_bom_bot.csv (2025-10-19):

Designator | Comment | Footprint | LCSC Part #
U21 | 74LVC125 | Package_SO:TSSOP-14_4.4x5mm_P0.65mm | C6059
U16 | AMS1117-3.3 | Package_TO_SOT_SMD:SOT-223-3_TabPin2 | C5346136
R3,R4 | 10k | Resistor_SMD:R_0805_2012Metric_Pad1.20x1.40mm_HandSolder | C5159708
R5 | 1k | Resistor_SMD:R_0805_2012Metric_Pad1.20x1.40mm_HandSolder | C5123594
U1 | CY62128ELL-45SXI | Package_SO:SSOP-32_11.305x20.495mm_P1.27mm | C2840304
U2,U4,U14 | 74HC00 | Package_SO:SO-14_3.9x8.65mm_P1.27mm | C699445
C20,C21 | 22pF | Capacitor_SMD:C_0805_2012Metric_Pad1.18x1.45mm_HandSolder | C525286
R2 | 0 | Resistor_SMD:R_0805_2012Metric_Pad1.20x1.40mm_HandSolder | C431818
R6 | 180 | Resistor_SMD:R_0805_2012Metric_Pad1.20x1.40mm_HandSolder | C25270
R1,R7 | 560 | Resistor_SMD:R_0805_2012Metric_Pad1.20x1.40mm_HandSolder | C429158
R8,R9,R10,R11 | 3.3k | Resistor_SMD:R_0805_2012Metric_Pad1.20x1.40mm_HandSolder | C407459
J1 | Micro_SD_Card_Det1 | components:CONN9_MSD-1_CUD | C381082
U5 | 74HC163 | Package_SO:SOIC-16_3.9x9.9mm_P1.27mm | C338758
C23 | 100nF | Capacitor_SMD:C_1206_3216Metric_Pad1.33x1.80mm_HandSolder | C309030
U8,U11 | 74HC273 | Package_SO:SOIC-20W_7.5x12.8mm_P1.27mm | C131486
C1,C2,C3,C4,C5,C6,C7,C8,C9,C10,C11,C12,C13,C14,C15,C16,C17,C18,C19,C22 | 0.1uF | Capacitor_SMD:C_0805_2012Metric_Pad1.18x1.45mm_HandSolder | C126469
U3,U18 | 74HC74 | Package_SO:SO-14_3.9x8.65mm_P1.27mm | C27597
U20 | 74HC85 | Package_SO:SOIC-16_3.9x9.9mm_P1.27mm | C5953
U13 | 74HC595 | Package_SO:SOIC-16_3.9x9.9mm_P1.27mm | C5947
U9,U10 | 74HC32 | Package_SO:SO-14_3.9x8.65mm_P1.27mm | C5632
U12 | 74HC165 | Package_SO:SOIC-16_3.9x9.9mm_P1.27mm | C5613
U6,U17 | 74HC138 | Package_SO:SOIC-16_3.9x9.9mm_P1.27mm | C5602
U7 | 74HC123 | Package_SO:SOIC-16_3.9x9.9mm_P1.27mm | C5597
U19 | 74HC02 | Package_SO:SO-14_3.9x8.65mm_P1.27mm | C5588

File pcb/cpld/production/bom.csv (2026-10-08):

Designator | Footprint | Quantity | Value | LCSC Part #
C1, C11, C12, C13, C14, C2, C3, C4, C5, C6, C8, C9 | 0805 | 12 | 0.1uF | C126469
C10 | 0805 | 1 | 100n
C23 | 1206 | 1 | 100uF | C309030
D1 | 0805 | 1 | ~{CS}
D2 | 0805 | 1 | MOSI
D3 | 0805 | 1 | MISO
J1 | CONN9_MSD-1_CUD | 1 | Micro_SD_Card_Det1 | C381082
J2 | ISA_CARD_EDGE_CONNECTOR_8BIT_Rev1 | 1 | Bus_ISA_8bit_AB_Rev0
R1 | 0805 | 1 | 10k | C5159708
R10, R11, R8, R9 | 0805 | 4 | 3.3k | C407459
R2, R3, R4 | 0805 | 3 | 180
RN1, RN3 | R_Array_Convex_4x0612 | 2 | 10k
SW1 | SW_DIP_SPSTx08_Slide_9.78x22.5mm_W7.62mm_P2.54mm | 1 | ADDR SEL
U1, U5 | SOIC-14_3.9x8.7mm_P1.27mm | 2 | 74HC00 | C699445
U10, U13 | SOIC-14_3.9x8.7mm_P1.27mm | 2 | 74HC74
U11 | SOIC-14_3.9x8.7mm_P1.27mm | 1 | 74HC08
U12 | SOIC-14_3.9x8.7mm_P1.27mm | 1 | 74HC04
U16 | SOT-223-3_TabPin2 | 1 | AMS1117-3.3 | C5346136
U2 | SOIC-14_3.9x8.7mm_P1.27mm | 1 | 74HCT32
U21 | TSSOP-14_4.4x5mm_P0.65mm | 1 | 74LVC125 | C7494906
U3 | SOIC-16_3.9x9.9mm_P1.27mm | 1 | 74HCT139
U4 | SOIC-16_3.9x9.9mm_P1.27mm | 1 | 74HC163 | C338758
U6 | SOIC-16_3.9x9.9mm_P1.27mm | 1 | 74HC165 | C5613
U7 | SOIC-16_3.9x9.9mm_P1.27mm | 1 | 74HC595 | C5947
U8 | SOIC-20W_7.5x12.8mm_P1.27mm | 1 | 74HCT688
U9 | SOIC-20W_7.5x12.8mm_P1.27mm | 1 | 74HCT245
X1 | Oscillator_DIP-14 | 1 | 16MHz

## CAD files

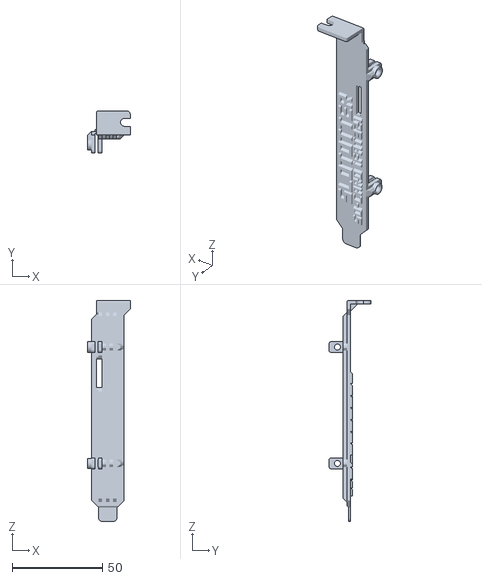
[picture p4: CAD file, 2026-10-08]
bracket/bracket-release-card-text.stl
23.6 x 23.5 x 122.5

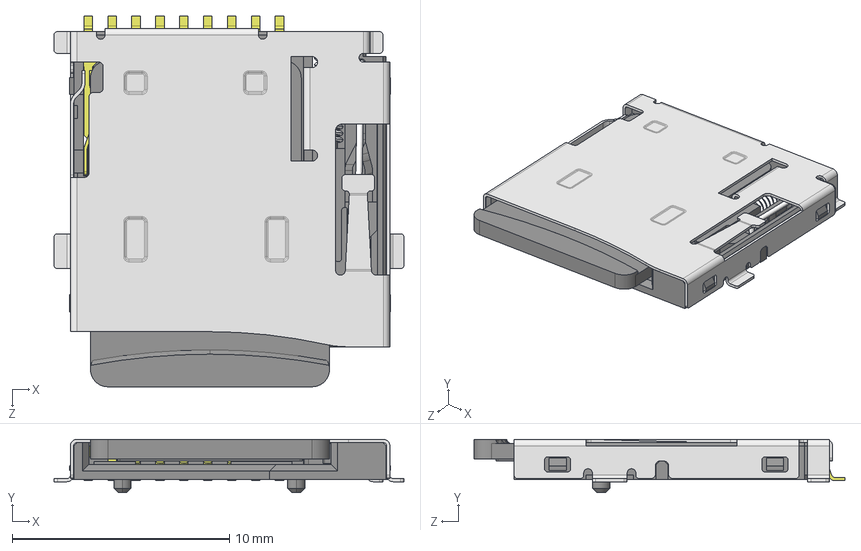
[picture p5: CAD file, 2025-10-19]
pcb/cpld/components/MicroSD_Socket.STEP
16.1 x 2.45 x 17.0 mm
Case^MicroSD_Socket
Insert^MicroSD_Socket
Brace^MicroSD_Socket
Spring^MicroSD_Socket
Lid^MicroSD_Socket
Pin_Middle^MicroSD_Socket x 5
Pin_Short^MicroSD_Socket
Pin_Long^MicroSD_Socket x 2
MicroSD_Card^MicroSD_Socket
Pin_CardIn^MicroSD_Socket

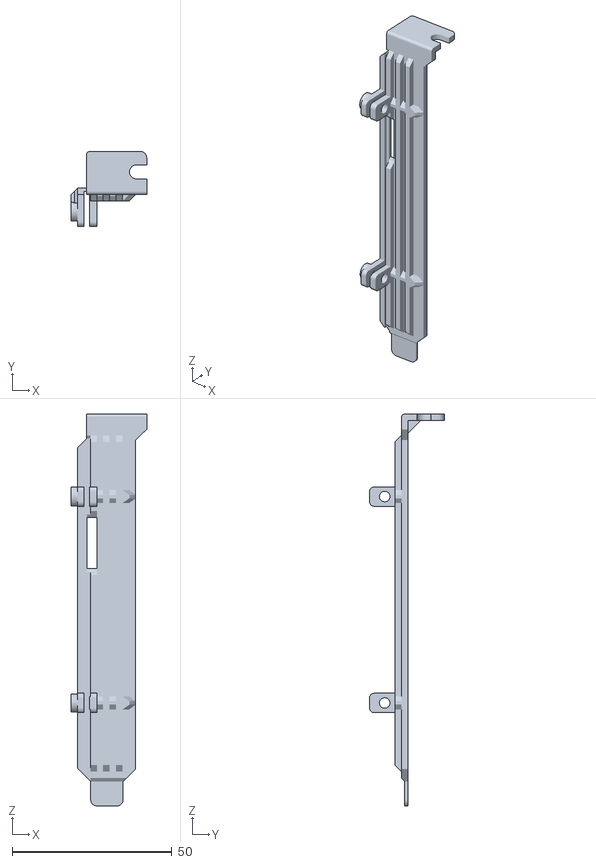
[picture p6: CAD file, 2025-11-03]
bracket/bracket-release-card.stl
23.6 x 23.5 x 122.5

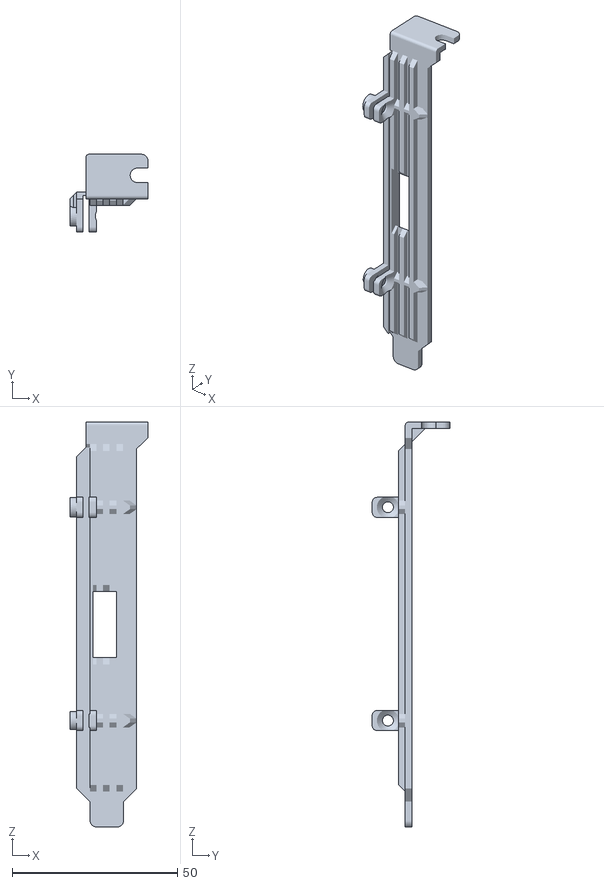
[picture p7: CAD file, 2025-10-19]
bracket/bracket-prototype-card.stl
23.6 x 23.5 x 122.5

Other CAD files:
buildenv/TC/WILDARGS.OBJ

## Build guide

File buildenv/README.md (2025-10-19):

# Build Environment

This folder contains the binaries of Borland's Turbo Assembler v2.0.1 and
Borland's Turbo C compiler v2.0. The binaries were produced using the install
disks obtained from the following links
* https://winworldpc.com/product/turbo-assembler/20
* https://winworldpc.com/product/borland-turbo-c/2x

**Disclaimer**: These binaries are provided here solely to reproduce a
historical build environment. To the best of my knowledge, Borland's Turbo
Assembler and Turbo C are no longer sold or supported and are generally regarded
as abandonware within the retro-computing community. However, they remain
proprietary software, and no explicit free-use licence has been issued by the
rights holder. If you reuse or redistribute these files, please ensure
compliance with applicable copyright laws.

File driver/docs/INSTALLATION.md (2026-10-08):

# OTTERSD 1.0.0

OTTERSD exposes the Slot-otter SD card as an ordinary DOS drive letter for
COPY, XCOPY, games and file managers. For browsing and copying files, we
recommend Nightwatch: https://github.com/ifilot/nightwatch

## Downloads and card preparation

OTTERSD-DOS.zip and the 360 KiB, 720 KiB and 1.44 MiB installation floppies
contain only OTTERSD.EXE, README.TXT, CONFIG.TXT and LICENSE.TXT. These are
data/install disks, not DOS boot disks.

Recommended: OTTERSD-FAT16-500MiB.zip, an empty 500 MiB FAT16 volume with
16 KiB clusters. Hardware trials showed faster writes than the earlier FAT32
configuration. Larger clusters reduce allocation/FAT work but use more space
for small files. Physical sectors remain 512 bytes.

Alternative: OTTERSD-FAT32-500MiB.zip, an empty 500 MiB FAT32 volume with
4 KiB clusters. Larger clusters at this capacity would produce too few
clusters for a valid FAT32 volume. Neither image contains files, directories,
utilities or markers. ZIP instructions/checksums are outside the SD filesystem.

Back up the card, extract the chosen ZIP and write its IMG to the ENTIRE
removable card with your image-writing tool. This replaces its partitions
and files: select the correct device carefully. Do not copy the IMG as a file
or reformat afterwards. You can copy files to the volume on Windows before
moving it to DOS. Use an SDHC/SDXC card at least 501 MiB in size: the whole
disk image includes a 1 MiB partition offset. Extra capacity on a larger
card remains outside the supplied partition. The SD images are not boot disks.
Install OTTERSD separately from the floppy or DOS ZIP.

## Install under DOS

1. Boot your existing DOS system. Copy the driver package to a local
   directory such as C:\OTTERSD. Do not load it from the SD drive it provides.
2. Merge these settings into CONFIG.SYS, preserving its other settings:

       LASTDRIVE=S
       FILES=40
       BUFFERS=10

3. Reboot, insert the card, and ensure S: is unused. Run:

       C:\OTTERSD\OTTERSD /DRIVE:S /PORT:330 /RW

   Port values are hexadecimal. Replace 330 with your configured ISA port.
   /RW enables writes and verifies them by reading back before reporting
   success. Use /RO instead for read-only access, also the default when
   neither option is supplied. FAT16/FAT32 detection is automatic.
4. Once the driver reports that the card is mounted, use DIR S:\, COPY,
   XCOPY, games or Nightwatch as you would with an ordinary DOS drive.
5. Add the loading command to AUTOEXEC.BAT for automatic installation.
   This is a TSR executable: do not use DEVICE=OTTERSD.EXE in CONFIG.SYS.
   Reboot when replacing an older resident driver.

Existing supported MBR volumes can also be used without imaging them.
/FAT16 or /FAT32 restricts mounting; neither formats or converts the card.

## Removal, replacement and memory

Close files and applications using the SD drive. Switch to the local disk
and unmount before removing the card:

    C:
    C:\OTTERSD\OTTERSD /UNMOUNT

Insert the replacement and run OTTERSD /MOUNT. /UNMOUNT keeps the driver
resident. To reclaim its approximately 42 KiB of conventional memory for a
game, run OTTERSD /UNLOAD after closing files and switching to a local drive.
Unloading flushes filesystem state and refuses unsafe conditions, including
open files or a later resident program hooking its interrupt chain.

Never use the legacy Navigator or raw-sector software on a mounted card.
Unmount first. OTTERSD /STATUS displays the current drive state.

## Performance options

Start with ordinary /RW. Installation-only options are:

- /SKIPFATCHECK: skip the full mirror comparison at mount. Modified FAT
  sectors and commit/unmount checks retain their comparisons.
- /NOVERIFY: skip successful post-write readback. CRC, status, identity and
  bounded recovery remain, but silent corruption can escape detection.

Read positions and metadata caches are automatic. Copy speed also depends
on CPU speed, the ISA interface and the destination disk.

## Requirements and diagnostics

Target: 8088/8086 or newer, MS/PC-DOS 3.1 through 6.x, Slot-otter ISA card,
SDHC/SDXC card, FAT16/FAT32 and 512-byte sectors. The driver uses approximately
42 KiB of conventional memory and needs no EMS or XMS. DOS 5 and 6.22 have
been tested in emulation; physical 8088/5150 testing remains pending.

Files use DOS short names or existing 8.3 aliases. GPT, extended partitions,
FAT12, exFAT, SDSC and long-name creation are unsupported. The supplied FAT16
root has 512 entries; subdirectories can grow. Windows long names consume
additional entries even when DOS uses their 8.3 aliases.

If installation fails, retain its complete output and run /STATUS. Report
version, DOS version, CPU/RAM, port, card model, filesystem, and the printed
DOS/SD error, stage, LBA, R1, token and poison fields. Do not keep retrying
writes after a failed or poisoned session.

Source and releases: https://github.com/ifilot/slot-otter
License: GNU GPL version 3 or later; see LICENSE.TXT.

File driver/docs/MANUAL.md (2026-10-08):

# OTTERSD: real hardware test

Use a spare SDHC/SDXC card. Writing the supplied image replaces its existing
partition and files. Keep a bootable recovery floppy and back up the PC's
CONFIG.SYS/AUTOEXEC.BAT. Run this procedure separately on SanDisk and Intenso,
starting with a newly imaged card each time. Physical 8088 testing remains
deferred; an 80286 with 1 MiB is the immediate hardware target.

This kit tests OTTERSD through DOS file APIs. It does not talk directly to the
ISA card and does not deliberately send invalid CRCs. Keep the earlier WTTEST
kit and logs separately; never run a raw card utility while this driver is
mounted. Compilation uses Turbo C/TASM; emulation testing boots genuine DOS.
Passing emulation does not qualify physical hardware.

Failed installation, /MOUNT and /STATUS print the retained SD diagnostic;
HWRT /INFO saves it to RWINFO.LOG even when the drive is offline.

## 1. Image and copy the kit using Navigator

Write OTTERSD.IMG as a whole-disk image to the spare card using your usual PC
image-writing tool. Select the correct removable device. Do not copy the IMG
file into an existing filesystem. The image contains a small FAT32 partition,
read fixtures, a root RW.TAG identity marker, and a KIT directory.

Boot the DOS PC without either resident driver installed. Use Navigator to
copy every file from KIT to a writable local directory, for example C:\OTTERSD
or A:\OTTERSD. Required files are OTTERSD.EXE, HWRT.EXE,
MANUAL.TXT, CONFIG.TXT, FILES.SHA and SOURCE.SHA. HWRT includes its own
process-exit child tests; no companion executable is needed. The OTTERSD.ZIP source/evidence archive is retained on your development PC.

Exit Navigator completely before installing the driver. The driver and
Navigator must not own the SD card at the same time. Keep the test card inserted.

## 2. Configure DOS, reboot, and install

Merge these settings into the local boot disk's existing CONFIG.SYS:

```
LASTDRIVE=S
FILES=40
BUFFERS=10
```

Preserve the other boot-disk settings. Do not use DEVICE=OTTERSD.EXE: this is a
TSR redirector executable. For this qualification run, install it manually
after each reboot. Remove any existing automatic OTTERFS/OTTERWR/OTTERSD installation
from AUTOEXEC.BAT for the duration of testing. S: must be unused.

Reboot. Change to the local kit directory and run:

```
OTTERSD /DRIVE:S /PORT:330 /RW > INSTALL.LOG
TYPE INSTALL.LOG
OTTERSD /STATUS > STATUS.LOG
TYPE STATUS.LOG
HWRT /INFO /PORT:330
```

Use the actual configured ISA base port instead of 330 if it differs; port
values are hexadecimal. Installation must report verified read/write and a
mounted card. Without /RW, OTTERSD installs read-only and write tests refuse
to proceed. Use /RO to select read-only explicitly. Both modes use the same consolidated
42,896-byte resident allocation. Use OTTERSD 1.0.0 and HWRT 1.0.0 from the SAME kit. Replace earlier executable
files in your local kit directory; update any old AUTOEXEC.BAT command names.

Keep the complete local directory for each card, and copy its logs to a
separate labelled directory before starting the next card. /INFO prints the
cached mounted CID, manufacturer/product/serial, capacity, driver/test versions
and mount phase timings. Compare those records when relaying logs. HWRT 1.0.0 also prints DOS SPACE:
the logical allocation-unit size, total/free counts and byte capacities.
The 500 MiB image uses 4 KiB physical clusters but reports 8 KiB logical
units to DOS, with free space rounded down by less than one logical unit.
Read-only mode reports zero writable free space.

Run HWRT from the local directory, never S:. It creates local logs itself;
do not redirect them onto the SD card. /INFO validates the image marker and
original read fixtures without writing the card. A local log failure stops
the test. DOS critical errors return FAIL instead of waiting at a prompt.

## 3. First write test

```
HWRT /TEST /ERASE /PORT:330
```

/ERASE is the explicit authorization to create/delete test files. It does not
format the disk. /TEST requires the supplied image marker and a writable,
mounted enhanced driver with no open resident files. An existing RWTEMP
directory stops the initial test: do not delete it and retry after a failure;
preserve the log, reboot and re-image the card.

Every checkpoint prints PASS or FAIL. Expected access/lock rejections can print
DOS ERROR lines followed by PASS; those lines are intentional negative tests.
Their function/AX records are the direct INT 21h results. C errno/DOS errno and
extended errors can be stale after direct interrupt calls or local logging.
The final HWRT RESULT must say PASS with ERRORLEVEL=0. The program stops at the
first unexpected failure, reports driver/transport details, and returns 1.
Setup/usage/local-log problems return 2.

The suite exercises file creation, boundary overwrite, append, zero gaps,
zero-length truncate/extension, duplicates and shared handles, region locks,
attributes/timestamps, directory creation/removal, cross-directory moves,
grown-directory wildcard deletion, 64 KiB-crossing buffers, process exit with
unclosed handles/locks, interleaved allocation/reclamation, 70,000-byte new
files, and all-zero/all-FF payloads. It preserves the original read fixtures.

Default writes are intentionally expensive: every 512-byte sector is CRC checked,
waited to completion, read back with CRC, and compared exactly. Mount/commit
also check FAT metadata. Large volumes and an 8088 can take considerable time.
PHASE and PROGRESS lines identify directory growth, child-exit cycles, cluster
allocation and streamed-file work. TIMING lines measure phases and total time.
Keep the last visible checkpoint if progress stops; do not reset merely because
a directory operation takes longer than a file read. Installation reports SD
and filesystem BIOS ticks separately. Mount timings are short-operation,
16-bit measurements: an hour-long mount or midnight rollover can distort them.
HWRT phase timing handles one midnight; keep individual runs below 24 hours.

Keep RWTEST.LOG, INSTALL.LOG and STATUS.LOG before rerunning anything.

## 4. Stress and memory checks

```
HWRT /STRESS /ERASE /PORT:330
HWRT /MEMORY /PORT:330
```

/STRESS first verifies existing results, then performs twenty cycles of
allocation, writing, exact readback, deletion and cluster reuse. It verifies
the permanent results and original fixtures again. Preserve RWSTRESS.LOG.

/MEMORY allocates and overwrites all free DOS memory, exercises the resident
driver while that memory is occupied, releases it, and verifies the files
again. Save work before this command. RWMEM.LOG reports the DOS resident MCB
and the observed private-stack use. Pattern scanning measures this run; it
does not prove a worst-case IRQ/stack bound on all machines.

## 5. Flush, reboot, and verify persistence

```
OTTERSD /UNMOUNT > UNMOUNT.LOG
TYPE UNMOUNT.LOG
```

Close every file/application using S: first. Ordinary close writes and verifies
its data/metadata, but deliberately keeps the volume dirty. Explicit commit or
unmount still compares full FAT mirrors before marking it clean. Do not reset
or remove the card after /STRESS until /UNMOUNT succeeds. A successful unmount
commits the volume and leaves it offline. Reboot without re-imaging the card. Install the
same executable and mode as in step 2, then run:

```
HWRT /VERIFY /PORT:330
```

/VERIFY checks the completion marker, exact saved data, exact EOFs and final
timestamp. It writes no SD data. Preserve RWVERIFY.LOG as the reboot result;
copy it to a separately named local file before later /VERIFY runs overwrite it.
On the modern PC, also inspect the created files and use a read-only filesystem
check before making repairs. A successful immediate readback is insufficient
evidence of persistence after reboot.

## 6. Empty slot and re-insertion

Only after a successful test and reboot verification:

```
HWRT /SWAP /PORT:330
```

Follow the displayed prompts. It unmounts first, asks you to remove the card,
checks that an empty-slot mount returns a bounded error, then asks you to
reinsert the SAME card. It explicitly remounts and verifies saved results.
RW.TAG is shared by kit images; it is not a unique physical-card identity.
Reinserting the same card is your responsibility during this step.
Preserve RWSWAP.LOG. Do not remove a mounted card during an ordinary write test.
Test the second brand separately with a fresh image and new local log copies.

## 7. Report results and failures

Return all logs, the card brand/model/capacity, DOS version, CPU/RAM, ISA port,
driver executable hash from FILES.SHA, CONFIG.SYS/AUTOEXEC.BAT, and the last
visible checkpoint. Label SanDisk and Intenso logs separately. HWRT includes
its source identifier and driver mode in each log.

The SD line reports diagnostic error, stage, absolute LBA, R1, response token,
status, poison and attempts. FIRST preserves the first failure of the latest
sector write, even if its retry succeeded; later writes replace that snapshot.
Counters are cumulative since the last mount. /MEMORY and /SWAP remount, so
their final counters can reset. LAST CALLBACK is sticky and may describe an
earlier expected rejection rather than the operation immediately before it.
verified counts verified 512-byte sector writes, including FAT and directory
metadata. transmissions counts payload transmissions; retries counts additional
attempts after successful recovery. These are not file-operation counts.
LBA/stage/R1 can reflect a later read while FIRST/attempts still belong to the
latest write. The fields are not necessarily one operation's atomic snapshot.
Fields from a diagnostic query with CF=1 are unavailable, not evidence of health.

| SD diagnostic | Meaning |
|---|---|
| 101 | timeout waiting for command/token/busy completion |
| 102 | received CRC mismatch or card rejected data CRC |
| 103 | command/data response rejected |
| 104 | nonzero card status after write |
| 105 | CRC-valid readback differs from intended sector |
| 106 | identity/initialization/recovery could not be established |
| 107 | unsupported capacity/address range |

Normal stages are SD command numbers. Stage 124 waits for the CMD24 data
response, 224 for accepted-write busy completion, 324 for CRC-rejection busy
completion. A readback mismatch usually has stage 17. Token FE means a data
packet arrived; CRC or exact-content validation can still fail. FF commonly
means no response/token. Clean R1/status alone does not prove write success.
Poison=1 blocks further sector reads and writes and takes the volume offline.
Three attempts means the initial attempt plus at most two
retries of the same frozen sector/LBA, only after identity and usable reads
have been reestablished. Failed verification can occur after a sector changed.

Do not repeatedly run write commands after a failure. Keep the log and card
contents for analysis. Verified sector writes are not a transaction: power
loss/removal can leave leaked clusters, duplicate rename entries or mismatched
FAT copies. The driver does not automatically repair such a volume and refuses
writable mounting of unclean volumes and inconsistencies detected by mount
preflight; it does not perform a global allocation/crosslink scan. Use a fresh expendable
image for the next write qualification run.

## Supported scope

DOS handle-based file operations and short aliases are the qualification target.
LFN creation, FAT12/16 SD volumes, SDSC cards, booting DOS from the SD card,
and general DOS server/network functions are outside this kit. Standard FCB
wildcard deletion is covered; FCB record-I/O/process-abort lifecycle is not
qualified. DOS 5 and 6.22 are the actual-kernel test targets. The resident source
retains older DOS ABI handling and 8086 instructions, but that is not equivalent
to physical 5150 or DOS 3 qualification.

## Optional copy-throughput comparison

Use the default verified mode for the first run. The new FAT cache reduces
repeated reads without removing write readback. Version 0.9 retains the
filesystem traversal and far-memory copy improvements, but restores the
complete 0.6 C SD transport after the reported physical 0.7 mounting failure.
Repeat the verified hardware run first; physical confirmation of the recovery
build is pending. For ordinary files, create a
fresh destination directory and use your DOS version's XCOPY, for example:

```
MD S:\COPY
XCOPY C:\SOURCE\*.* S:\COPY /S /E
OTTERSD /UNMOUNT
```

Time the copy separately from installation and unmount. Unmount still audits
complete enabled FAT mirrors. Check the copied files after reboot, preferably
also with an independent byte comparison on your modern PC. Record source byte
count, elapsed time, card/CID, cluster size, mode, and the full installation log.
DOS5 XCOPY can return 1 after traversing an empty directory even when files were
copied; the automated tests compare this against an HDD-only control and verify
every byte. An exit code alone is insufficient for that case.

For a separate readback-disabled experiment, successfully unmount, reboot, then
install with:

```
OTTERSD /DRIVE:S /PORT:330 /RW /NOVERIFY > INSTALL.LOG
OTTERSD /STATUS
```

This mode can miss silently incorrect writes. It retains CRC, response/busy,
CMD13 status, identity and bounded recovery checks, but does not automatically
read and compare each completed write. It is fixed for that installation;
/MOUNT does not change it. Use a spare card and independent comparison after
reboot. HWRT prints the policy, and /VERIFY still compares saved test data even
in this mode. Its legacy `verified` counter then counts completed sector calls,
not sector readbacks. A clean FAT audit does not verify the contents of files.

There is no additional cache buffer or deferred writeback. The test image uses
512-byte clusters to exercise allocation heavily; the automated XCOPY gates
also exercise 4 KiB clusters, which require fewer FAT updates. Reformatting a
card for larger clusters is a separate operation; it is not required to use
the filesystem improvements or /NOVERIFY.

## Reclaim memory before running a game

The installer releases its temporary code, heap and startup stack automatically.
OTTERSD 1.0.0 retains 42,896 bytes of conventional memory including its PSP.
`/UNMOUNT` makes the drive offline but does not reclaim that memory. `/UNLOAD`
commits any closed-file changes, restores the drive's original DOS state and
interrupt vector, and releases the entire resident memory block.

Install this kit's OTTERSD.EXE and HWRT.EXE on your local hard disk; reboot once
to replace an older resident driver. Run games from your hard disk after unloading.
Copy any required game files from S: first. Exit programs accessing S:, close SD
files, and change to a local drive. For example:

```
C:
CD \OTTERSD
MEM /C > BEFORE.LOG
OTTERSD /UNLOAD
IF ERRORLEVEL 1 ECHO Unload failed - read the message before proceeding
MEM /C > AFTER.LOG
CD \DUNE2
DUNE2
```

MEM is supplied by later MS-DOS versions, not this kit; omit those two lines if
it is unavailable. Compare its largest executable program size and conventional
free memory. Successful unload prints "resident memory released" and returns
ERRORLEVEL 0. `/STATUS` then reports "not resident" (ERRORLEVEL 1); S: is unavailable.
No reboot or `/UNMOUNT` is needed before a successful `/UNLOAD`.

After leaving the game, reload from the local kit directory using the original
installation options:

```
C:
CD \OTTERSD
OTTERSD /DRIVE:S /PORT:330 /RW
OTTERSD /STATUS
HWRT /INFO /PORT:330
```

Use `/RO` or `/RW /NOVERIFY` if that was your chosen policy. Reload initializes
the card and validates the filesystem again. `/MOUNT` cannot reload a driver
that has been removed from memory.

Unload refuses while S: is the current drive or any SD file is open, including
redirected output on S:. Run the command and store logs on the local disk. If a
later TSR hooks INT 2F, remove that TSR first using its own supported procedure,
or reboot; OTTERSD never cuts it out of the interrupt chain. Installing OTTERSD
last usually allows unloading first. A failed write commit, poisoned card session, or card removal before a dirty
session was committed leaves OTTERSD resident: preserve `/STATUS` diagnostics and reboot to
recover. Do not remove the card or force-free its memory after that warning.

For the first hardware unload check, perform the normal /INFO and /VERIFY
checks, record MEM output before/after unloading, run Dune II locally, then
reload and repeat /INFO and /VERIFY. Keep the two MEM logs and any refusal
messages. Unloading recovers OTTERSD's allocation; DOS buffers, LASTDRIVE data,
and other drivers remain. It cannot guarantee a game will fit if those other
allocations still leave insufficient memory. Genuine DOS tests independently
check total free memory and the largest executable block return to their exact
pre-install values over three install/unload cycles, with open-handle and later
hook refusals, plus independently verified committed file contents and FATs.

## Optional faster mounting

Use the installation-only option /SKIPFATCHECK with /RW:

```
OTTERSD /DRIVE:S /PORT:330 /RW /SKIPFATCHECK
OTTERSD /STATUS
HWRT /INFO /PORT:330
```

The default is a full comparison of enabled FAT copies before writable mounting.
/SKIPFATCHECK skips that scan at installation and later /MOUNT operations; it
still compares the first FAT sector because clean/error flags share that sector
with allocation entries. Geometry, card capacity/identity, backup boot, primary
clean/error flags and FSInfo checks remain. FAT sectors are compared before
modification; dirty-session commit, /UNMOUNT and /UNLOAD still compare the full
FATs before marking the volume clean. These operations can therefore still take
time after writes. An unmodified, clean session needs no full commit scan.

On the 500 MiB image, this avoids roughly 1 MiB of mount reads. The startup
message identifies the skipped comparison and prints a warning; /STATUS and
HWRT logs record the policy. Compare MOUNT TIMING filesystem_ticks for strict
and fast installations on the same clean card to measure your hardware gain.
Unload the previous instance before changing policy. The option survives
unmount/remount but must be supplied again after a complete /UNLOAD.

A mismatch outside the first FAT sector can now remain undetected at mount.
It will be detected if that FAT sector is modified or during a dirty-session
commit; some writes may already have occurred before this failure. A clean
flag alone does not prove that the two FATs agree. The driver does not repair
or choose a winning FAT. Use a checked, expendable card for the first test.
/SKIPFATCHECK does not permit dirty volumes or bypass filesystem-format checks.

/NOVERIFY and /SKIPFATCHECK are independent. Both can be supplied with /RW;
CRC/status checks remain, but /NOVERIFY also removes write readback. For the
first fast-mount hardware run, keep readback enabled and perform /INFO,
/TEST /ERASE, /VERIFY, then /UNLOAD and a fresh-boot /VERIFY. Save the local
logs, status output and mount timings. Never store these logs on S:.

/RO already skips the full comparison, so /RO /SKIPFATCHECK is rejected.
Duplicate /SKIPFATCHECK and combinations with /STATUS, /MOUNT, /UNMOUNT or
/UNLOAD are rejected. This is a load-time policy, not a command that alters a
running driver's policy. Updating this kit requires replacing both local
executables and unloading the old version with its matching old executable,
or rebooting once. No card reformat is necessary.

## FAT16 and format restrictions (0.13)

The same OTTERSD executable mounts FAT16 and FAT32 automatically. `/FAT16` or
`/FAT32` may be added to the installation command to require that format. Do
not combine them; they are installation options, not formatting commands.
`OTTERSD /STATUS` and `HWRT /INFO` report the mounted format and restriction.
A card of the wrong format remains offline; the restriction also applies
when subsequently mounting another card. Omit both options to allow either.

The alternative `driver/dist/FAT16/OTTER16.IMG` provides a 500 MiB FAT16
partition with 16 KiB clusters. Use its matching KIT and follow the same test
steps in this manual. FAT16 has a fixed 512-entry root directory on this image;
create subdirectories for larger collections. FAT32 retains its growing root.
An exhausted FAT16 root returns disk full without extending the root or FAT.
FAT16 does not have FAT32 FSInfo or backup BPB sectors; their byte offsets are
not interpreted as metadata. Mirror, CRC, clean/error-flag, identity and write
readback checks remain in force for both formats.

## Read caching (0.15)

Both modes cache four 512-byte FAT sectors and two 512-byte directory sectors,
separately from the one-sector file-data buffer. `/RW` now retains each open
handle's cluster cursor between read requests. Writes invalidate cursors before
attempting their sector stores and invalidate matching cached sectors. Shared
handles still refresh file metadata; backward seeks restart traversal as needed.
Card identity checks and CRC checks remain. Mutation preflight discards cached
evidence and reads fresh directory/FAT data. There is no deferred writeback.

Use the existing unmount procedure before Navigator or any raw-sector tool
changes the mounted card. There is no new cache option and no need to reformat.

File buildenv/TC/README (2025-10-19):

                        WELCOME TO TURBO C 2.0
                        ----------------------

This README file contains important, last minute information
about Turbo C 2.0. The HELPME!.DOC file on the COMPILER/UTILITIES
disk also answers many common Technical Support questions.

TABLE OF CONTENTS
-----------------
  1. How to Get Help
  2. Installation
  3. Important Notes
  4. Corrections to the Manuals
  5. Additional Notes
  6. Notes for Turbo Prolog Users
  7. Files on the Disks

 1. HOW TO GET HELP
-------------------

  If you have any problems, please read this file, the
  HELPME!.DOC file, and the Turbo C manuals first. If you still
  have a question and need assistance, help is available from
  the following sources:

  1. Type GO BOR on the CompuServe bulletin board system for
     instant access to the Borland forums with their libraries of
     technical information and answers to common questions.

     If you are not a member of CompuServe, see the enclosed special
     offer, and write for full details on how to receive a free
     IntroPak containing a $15 credit toward your first month's on-
     line charges.

  2. Check with your local software dealer or users' group.

  3. Write to us at the following address:

     Borland International
     Turbo C Technical Support
     1800 Green Hills Road
     P.O. Box 660001
     Scotts Valley, CA  95066-0001

     Please remember to include your serial number or we will be
     unable to process your letter.

  4. If you have an urgent problem that cannot wait and you have sent
     in the license agreement from the front of your manual, you may
     call the Borland Technical Support Department at (408) 438-5300.
     Please have the following information ready before calling:

     a. Product name and serial number on your original distribution
        disk.  Please have your serial number ready or we will be
        unable to process your call.

     b. Product version number. The version number for Turbo C is
        displayed when you first load the program and before you
        press any keys.

     c. Computer brand, model, and the brands and model numbers of
        any additional hardware.

     d. Operating system and version number. (The version number can
        be determined by typing VER at the MSDOS prompt.)

     e. Contents of your AUTOEXEC.BAT file.

     f. Contents of your CONFIG.SYS file.

 2. INSTALLATION
----------------
  The INSTALL/HELP/BGI disk contains a program called
  INSTALL.EXE that will assist you with the installation of
  Turbo C 2.0. There are three options for installation:

  1. Hard Disk - This option allows you to pick the subdirectories
     where the files will be loaded. It will create a TURBOC.CFG
     file based on those directories.

  2. Update from TC 1.5 - This allows for an easy update from version
     1.5.  After the files are copied, all the installed options
     from your current TC.EXE will be transferred to the new one.
     This is especially useful if you have modified the colors or
     editor keys.

  3. Floppy Disk - This option will build either a command line or
     Integrated Development Environment version for a two drive
     system. Be sure to have three formatted disks ready before
     you start.

  To start the installation, change your current drive to the one
  that has the install program on it and type INSTALL.  You will
  be given instructions in a box at the bottom of the screen for
  each prompt. For example, if you will be installing from drive
  A:, type:

    A:
    INSTALL

  You should read the rest of this README file to get further
  information about this release before you do the installation.

 3. IMPORTANT NOTES
-------------------

  o The file HELPME!.DOC contains discussions of common questions
    and answers concerning Turbo C 2.0. You should consult it for
    answers to problems that aren't covered in this file or in
    the manuals.

  o If you are running INSTALL or TCINST on a laptop or any other
    system that uses an LCD or composite display, you should set
    your system to black and white mode before running INSTALL
    or TCINST. You can do this from DOS with the following command
    line:

      mode bw80

    or, you can force INSTALL or TCINST to come up in black and
    white mode by using the /b switch:

      tcinst /b

  o /P PARAMETER FOR TC.EXE. A new command-line switch controls
    palette swapping on EGA video adapters. Using this switch

      tc /p hello

    is recommended only when the user program modifies the EGA
    palette registers. When /P is specified, the EGA palette will be
    restored each time the screen is swapped. In general, you don't
    need to use this switch unless your program modifies the EGA
    palette registers, or unless your program uses BGI to change
    the palette.

  o A program that takes over interrupt 9 cannot be debugged
    with the integrated debugger. Use the standalone Turbo Debugger
    instead.

  o exec() WITH NOVELL NETWORK. Versions of the Novell network
    system software earlier than 2.01-2 do not support a DOS
    call used by exec(), spawn(), and system(). If you are using
    the Integrated Development Environment to run a program that
    uses any of these functions and you have early Novell system
    software, run the program from DOS. To do this from the
    Integrated Development Environment you can use Alt-F/O.

  o If you used the INSTALL program to upgrade from version 1.5,
    or if you used CINSTXFR to transfer options from an
    installation of version 1.5, check the setting of the
    standard stack frame option in the Integrated Development
    Environment (Alt-O/C/C/S). If you are going to use the
    integrated debugger this option should be turned ON.

  o If you are having problems with the call stack or qualified
    names, make sure you have compiled with the standard stack
    frame option turned on.

  o The ANSI draft has changed the syntax of labels.  A label now
    must always be followed by a statement.  This means that code
    like this is no longer accepted:

      {
        .
        .
        .
        jump_label:
      }

    If you have code like this, change it to look like this:

      {
        .
        .
        .
        jump_label:
        ;       /* need a statement here! */
      }

  o TCC has a switch to specify which assembler to look for. By
    default, it will look for TASM.EXE. If you want to use a
    different assembler, use -E<filename>, as described in the
    Reference Guide.

  o When using THELP on an AT&T 6300, be sure to use the /L25
    command-line option, as described in the file THELP.DOC.

  o When you use qualified variable names as described on page
    57 of the User's Guide you don't need to use the module
    name to access a variable that is local to a global
    function. The module name is only needed when you access a
    static variable or a variable that is local to a static
    function.

  o Because of the limited memory available in the Tiny model,
    it no longer supports graphics functions.

  o The Version 1.5 graphics drivers (*.BGI) are not compatible
    with the Version 2.0 graphics library. Use the graphics drivers
    distributed with Version 2.0.

  o When used with a Zenith Z-449 card, the BGI autodetection code
    will always select the 640X480 enhanced EGA mode. If you are
    using the Z-449 with a monitor that is not compatible with
    this mode, it will be necessary to override the GraphDriver
    and GraphMode parameters used in the BGI initgraph() call.

 4. CORRECTIONS TO THE MANUALS
------------------------------

REFERENCE GUIDE:

 Page

 159  The prototype for the function getdefaultpallette() is
      incorrect. It should be

        struct palettetype * far _Cdecl getdefaultpalette( void );

USER'S GUIDE:

 Page

  57  In the section entitled "Qualifying Variable Names," the
      last sentence should read "...need to type only myfunc.myvar."

  66  The directions for compiling the WORDCNT program are
      incorrect. There is no WORDCNT.PRJ file; all you need to do
      is load the file WORDCNT.C into the editor. Once you have
      done that, the rest of the instructions are correct.

 5. ADDITIONAL NOTES
--------------------

  5.1 NOTES FOR VERSION 1.0 & 1.5 USERS
  -------------------------------------

  o You must use the Version 2.0 libraries with the 2.0 compilers.

  o The Integrated Development Environment no longer displays the
    message "Press any key to return to Turbo C..." when your
    program terminates. Instead, at the end of your program the
    User screen is replaced by the Integrated Development
    Environment. To view the User screen, press Alt-F5 or
    select Alt-R/S. When you are viewing the User screen,
    pressing any key will return you to the Integrated
    Development Environment.

  o A new pseudo-variable has been added. _FLAGS now contains the
    value of the flags register so you can test the flags at any
    point in your program.

  o The ssignal() and gsignal() functions are no longer
    supported. See the section in this README on how to convert
    programs that use them.

  o The cprintf() function now works as documented. It does not
    translate line-feeds into CR/LF combinations.

  o Some compatibles had a problem under Version 1.5 because it
    used interrupt 18H. Version 2.0 does not use this interrupt,
    so you shouldn't encounter this problem anymore.

  o The program TCINST.COM in Version 1.0 has been changed to an
    .EXE file. You should delete the TCINST.COM program before
    trying to run the new TCINST.EXE. Otherwise, MS-DOS will actually
    run the old one.

  o The FILE structure for streams in Version 1.0 (but not 1.5) has
    been changed, so that the function tmpfile() could be implemented.
    You should recompile any modules that use stream I/O.

  5.2 THELP
  ---------

  THELP is a memory-resident utility program that gives you
  access to the Turbo C context-sensitive help system from any
  program. You don't need to use THELP if you're in the
  Integrated Development Environment, but it is especially useful
  if you use the command line compiler and your own text editor,
  or if you are debugging with the standalone Turbo Debugger. To
  use THELP, load THELP.COM into memory by typing at the DOS
  command line:

    thelp

  You activate ("pop-up") THELP by typing its hot key -- by
  default numeric keypad <5>. All Turbo C help commands apply
  (F1, Ctrl-F1, Alt-F1). For a complete description of THELP,
  refer to THELP.DOC in the Documentation Subdirectory.

  5.3 USING CINSTXFR.EXE
  ----------------------

  Your Turbo C 2.0 package contains a program named CINSTXFR.EXE,
  which can be used to transfer the configuration of the
  Integrated Development Environment from your copy of Turbo C
  1.5 (not for 1.0) to your new installation of Turbo C 2.0. This
  program is run automatically by INSTALL.EXE if you select the
  option to "Update Hard Drive Copy of Turbo C 1.5 to Turbo C 2.0."
  If you prefer to do this yourself, you can run CINSTXFR.EXE from
  the DOS command line.

  CINSTXFR.EXE takes two arguments: the first is the name of your
  Turbo C 1.5 Integrated Development Environment file (usually
  TC.EXE), and the second is the name of your Turbo C 2.0
  Integrated Development Environment file (also usually TC.EXE).
  Either one of these names can also include a path name.

  For example, if your copy of the Turbo C 1.5 Integrated
  Development Environment file is named TC.EXE and is in a
  directory named \TURBOC and your copy of the Turbo C 2.0
  Integrated Development Environment file is also named TC.EXE
  but is located in a directory named \TC2, the command line to
  copy the configuration from 1.5 to 2.0 would look like this:

    CINSTXFR \TURBOC\TC.EXE \TC2\TC.EXE

  This will transfer all the options that you installed in
  your copy of Turbo C 1.5 to your copy of Turbo C 2.0.

  CINSTXFR.EXE does not work with Turbo C 1.0. If you are
  upgrading from Turbo C 1.0, you will have to install the
  options yourself.

  5.4 CHANGED SWITCHES FOR OBJXREF
  --------------------------------

  OBJXREF is an object module cross reference utility and is
  described on page 528 of the Turbo C Reference Guide.
  The /O option (object files directory) has been changed to the
  /D (directories) option. The switch now allows for multiple
  search directories to be specified. The new syntax is:

    OBJXREF /Ddir1[;dir2[;dir3]]
                or
    OBJXREF /Ddir1 [/Ddir2] [/Ddir3]

  OBJXREF will search each of the directories in the specified
  order for all object and library files. If no /D option is
  used, only the current directory will be searched. However,
  if a /D option is used, the current directory will NOT be
  searched unless it is included in the directory list. For
  example, to first search the BORLAND directory for files and
  then search the current directory, you would type

    OBJXREF /Dborland;.

  If multiple search directories are specified and a file
  matching the file specification is found, OBJXREF will include
  the file as part of the cross-reference. OBJXREF will only
  continue to search the other directories for the same file
  specification if the file specification contains wildcards.

  A new option has been added to allow you to specify an output
  file where OBJXREF will send any reports generated. The new
  option is the /O option, and has the following syntax:

    OBJXREF myfile.obj /RU /Ofilename.ext

  By default, all output is sent to the console.

  5.5 CONVERSION INFORMATION FOR ssignal() AND gsignal()
  ------------------------------------------------------

  Note: The C library and SIGNAL.H no longer support the ssignal()
  and gsignal() functions.

  ssignal() and gsignal() were from the old UNIX System III
  days. The ANSI standard no longer supports them nor does the
  current UNIX System V Interface Definition specification. To
  ease portation problems for people moving older code to Turbo
  C, we supply the source for the functions that came with TC
  1.0 and TC 1.5. Also, the following discussion describes how
  code can be converted to do the same sort of things that
  ssignal() and gsignal() do without actually using them.

  NOTE: The constants defined in SIGNAL.H for SIG_IGN and
        SIG_DFL are different from the constants that were in
        TC 1.0 and TC 1.5.

  By using a globally declared array of function pointers, you
  can simulate the actions of ssignal() and gsignal() by using
  the following macros. Notice how the global table entry [0] is
  used as a temporary variable in the ssignal macro allowing the
  macro to swap the values and still return the original one.

    int (*_sigTable[16]) =
        {
        SIG_IGN, SIG_IGN, SIG_IGN, SIG_IGN,
        SIG_IGN, SIG_IGN, SIG_IGN, SIG_IGN,
        SIG_IGN, SIG_IGN, SIG_IGN, SIG_IGN,
        SIG_IGN, SIG_IGN, SIG_IGN, SIG_IGN,
        };

    #define ssignal(num, action) \
    ( \
    (((num) < 1) || ((num) > 15)) ? SIG_DFL : \
      ( \
      (_sigTable[0] = _sigTable[(num)]),  /* List of actions     */ \
         _sigTable[(num)] = (action),     /* The last expression */ \
            _sigTable[0]                  /* is the return value */ \
      ) \
    ) \

    #define gsignal(num) \
    ( \
    (((num) < 1) || ((num) > 15)) ? 0 : \
      ( \
      (_sigTable[(num)] == SIG_IGN) ? 1 : \
         ( \
           (_sigTable[(num)] == SIG_DFL) ? 0 : (*_sigTable[(num)])() \
      ) \
    ) \
   ) \

 6. NOTES FOR TURBO PROLOG USERS
--------------------------------

  o If you are linking C code with programs generated by Turbo
    Prolog 2.0, use the file INIT.OBJ provided on the
    INSTALL/HELP/BGI disk of the Turbo C 2.0 package instead of
    the file provided with Turbo Prolog 2.0.  There have been some
    changes made in Turbo C 2.0 that require the use of this new file.

  o If your C code uses floating point math and you link with the
    emulator library, Prolog will not automatically detect a math
    coprocessor chip. If you want to force the program to use the
    coprocessor, link it with FP87.LIB instead of EMU.LIB.

 7. FILES ON THE DISKS
----------------------

  INSTALL/HELP/BGI
  ----------------
  INSTALL  EXE  -  Installation program
  README   COM  -  Reads this README
  TCHELP   TCH  -  Help file for Turbo C
  THELP    COM  -  Pop-up utility to access TCHELP.TCH
  THELP    DOC  -  Documentation for THELP.COM
  UNPACK   COM  -  Program to unpack the ARC files
  OBJXREF  COM  -  Object file cross reference utility
  C0H      OBJ  -  Huge model startup code
  MATHH    LIB  -  Huge model math library
  CH       LIB  -  Huge model run-time library
  GETOPT   C    -  Parses options in command line
  HELLO    C    -  Example Turbo C program
  MATHERR  C    -  Source code for handling math library exceptions
  SSIGNAL  C    -  Source code for ssignal and gsignal functions
  CINSTXFR EXE  -  Program to copy TC 1.5 installation to TC 2.0
  INIT     OBJ  -  Initialization code for use when linking with Prolog

  BGI      ARC  -  BGI drivers and fonts
    BGIOBJ   EXE - Conversion program for fonts and drivers
    ATT      BGI - Graphics driver for ATT400 graphics card
    CGA      BGI - Graphics driver for CGA
    EGAVGA   BGI - Graphics driver for EGA and VGA
    HERC     BGI - Graphics driver for Hercules
    IBM8514  BGI - Graphics driver for IBM 8514 graphics card
    PC3270   BGI - Graphics driver for PC3270
    GOTH     CHR - Font for gothic character set
    LITT     CHR - Font for small character set
    SANS     CHR - Font for sansserif character set
    TRIP     CHR - Font for triplex character set
    BGIDEMO  C   - Graphics demonstration program

  STARTUP  ARC  -  ARC file with startup source code and related files
    RULES    ASI - Assembler include file for interfacing with Turbo C
    C0       ASM - Assembler source for startup code
    SETARGV  ASM - Assembler source code for parsing the command line
    SETENVP  ASM - Assembler source code for preparing the environment
    BUILD-C0 BAT - Batch file for building the startup code modules
    MAIN     C   - Alternative, stripped-down C main file
    EMUVARS  ASI - Assembler variable declarations for emulator
    WILDARGS OBJ - Object code for module to expand wildcard arguments

  EXAMPLES ARC  -  Various C examples code
    CPASDEMO PAS - Pascal program that demonstrates Turbo Pascal 4.0 -
                   Turbo C interface
    CPASDEMO C   - C example module for the Turbo Pascal 4.0 - Turbo C
                   interface demonstration
    CTOPAS   TC  - Configuration file for use with TC.EXE that
                   creates Turbo C modules in the correct format
                   for linking with Turbo Pascal 4.0 programs
    CBAR     C   - Example function to be used with PBAR.PRO
    PBAR     PRO - Example Turbo Prolog program demonstrating interface
                   with Turbo C
    WORDCNT  C   - Example program demonstrating source level debugging.
                   NOTE: DO NOT RUN THIS PROGRAM WITHOUT READING
                         THE DISCUSSION IN THE MANUAL. IT CONTAINS
                         DELIBERATE ERRORS.
    WORDCNT  DAT - Data file for use by WORDCNT.C

  MCALC    ARC  -  Mcalc sources and doc
    MCALC    DOC - MicroCalc documentation
    MCALC    C   - MicroCalc main program source code
    MCINPUT  C   - MicroCalc input routines source code
    MCOMMAND C   - MicroCalc commands source code
    MCPARSER C   - MicroCalc input parser source code
    MCUTIL   C   - MicroCalc utilities source code
    MCDISPLY C   - MicroCalc screen display source code
    MCALC    H   - The header file for MicroCalc
    MCALC    PRJ - The MicroCalc project file

  README        -  This file

  COMPILER/UTILITIES
  ------------------
  TC       EXE  -  Turbo C Compiler
  TCCONFIG EXE  -  Program to convert configuration files
  MAKE     EXE  -  Program for managing projects
  GREP     COM  -  Turbo GREP program
  TOUCH    COM  -  Program that updates a file's date and time
  TCC      EXE  -  Command line version of Turbo C Compiler
  CPP      EXE  -  Turbo C preprocessor
  TCINST   EXE  -  Installation program for TC.EXE
  TLINK    EXE  -  Borland Turbo Linker
  HELPME!  DOC  -  Common questions and answers

  HEADER FILES/LIBRARIES
  ----------------------
  C0S      OBJ  -  Small model startup code
  C0T      OBJ  -  Tiny model startup code
  C0L      OBJ  -  Large model startup code
  MATHS    LIB  -  Small model math library
  MATHL    LIB  -  Large model math library
  CS       LIB  -  Small model run-time library
  CL       LIB  -  Large model run-time library
  EMU      LIB  -  8087 emulator library
  GRAPHICS LIB  -  Graphics library
  FP87     LIB  -  8087 library
  TLIB     EXE  -  Borland Turbo Librarian
  ???????? H    -  Turbo C header files
  <SYS>         -  Subdirectory with SYS\*.H header files
  C0C      OBJ  -  Compact model startup code
  C0M      OBJ  -  Medium model startup code
  MATHC    LIB  -  Compact model math library
  MATHM    LIB  -  Medium model math library
  CC       LIB  -  Compact model run-time library
  CM       LIB  -  Medium model run-time library

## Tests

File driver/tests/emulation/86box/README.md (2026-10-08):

# Slot-otter in 86Box

This source adapter adds an 8-bit ISA Slot-otter card to the IBM 5150 (both
motherboard revisions) and IBM XT machine initializers. It uses the register
directions documented in the card schematic, an SDHC SPI command model, and a
raw FAT32 image opened **read-only**. It does not model the electrical timing of
the card's clock-generation circuit.

The adapter is compiled into a separate 86Box build. It is not a runtime plugin
and does not add a selectable card to the stock 86Box UI. The integration script
validates its patch locations and can be run repeatedly without duplicate hooks.

From this project's root, with your own 86Box source checkout:

```sh
python3 driver/tests/emulation/86box/install.py /path/to/86Box
```

Build that checkout following [86Box's build instructions](https://86box.readthedocs.io/en/latest/dev/buildguide.html).
The installer copies all three required C/header files; the resulting emulator
does not depend on this repository at runtime. API compilation was checked
against the official 86Box source headers. A complete 86Box boot has not yet been
validated here; the same card model has protocol tests and a DOSBox adapter for
testing it with actual DOS.

With 86Box closed, add this section to the machine's configuration file:

```ini
[Slot-otter]
base = 0330
image = /absolute/path/to/card.img
```

An empty image setting represents an absent card; OTTERSD still installs offline.
The shared model supports CMD10 CID checks and a socket replacement API, but this
adapter does not yet expose runtime insertion/ejection controls in the 86Box UI. Configure an IBM PC 5150,
8088 at 4.77 MHz, CGA or MDA, and 640 KiB RAM including ISA memory expansion.
Start with MS-DOS 6.22 to match the validated DOS tests; then try DOS 3.1/3.3.
Use your own BIOS ROMs and bootable DOS images. Load `OTTERSD` as described in
[the driver README](../../../README.md).

For a memory-constrained test, reduce conventional RAM to 256 KiB and measure
the free memory after DOS and the driver load. No EMS or XMS is required by the
driver. A 256 KiB configuration is a test target, not a verified minimum.

Run `tests/PROBE.C` (compiled to `PROBE.EXE`) and test `DIR`, `TYPE`, binary `COPY`
and `HELLO.COM` using the image made by `tests/fixture.py`. Compare the image's
SHA-256 before and after the run. Port `0330` must not be shared with an MPU-401
or another emulated ISA device.

The device API is documented by [86Box](https://86box.readthedocs.io/en/latest/dev/api/device.html).

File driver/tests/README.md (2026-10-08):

# Consolidated test infrastructure

Run `python3 driver/validate.py` to run host tests, coverage and mutations,
build OTTERSD.EXE and HWRT.EXE together, and package a candidate release.
Use `--full --dosbox PATH --boot-image DOS5 --boot-image DOS622` for actual DOS
read-only/CLI/EXEC/swap, write fault profiles, tester guards and final-image
stress/memory/reboot checks. All images are private copies. Physical testing
follows [the manual](../docs/MANUAL.md); the source tree is standalone from src.

- `kit_fixture.py`: one shared FAT32 image builder used by host/native/release
  tests; preserves known patterns, backup BPB and FSInfo. `fixture.py` supplies
  the basic fragmented read fixture. No old utility builder is imported.
- `emulation/`: shared card model and DOSBox/86Box adapters. Required for
  protocol/fault coverage; these are test tools, not resident code.
- `reference/`: historical CRC diagnostics and FAT routines compiled as host
  libraries to preserve independent regression/fault checks. Also contains the
  old read transport exercised by the native SDPROBE. These files have no
  standalone installer/build/package workflow and no released executables.
- `test_*.py`, `*_mutations.py`: production/reflection safety and mutation gates.
- `hardware.py`: native harness for the one public HWRT tester, including guards
  and a private emulator swap-input wrapper absent from the real executable.
- `integration.py`, `rw_integration.py`: internal DOS API/CLI/transport probes
  against the CURRENT OTTERSD executable. CLIPROBE uses a large inherited DOS
  environment and checks exit status, vector restoration and allocation cleanup.

`python3 driver/tests/run.py --coverage /tmp/coverage --mutations` runs host
checks alone. Its optional `--build` builds the canonical driver/tester pair.
PORTBODY.H is shared with the far installer; exhaustive tests cover its actual
parser. Coverage floors and behavioral mutation counts remain enforced.

Independent mtools comparisons and fsck.fat -n check images after DOS operations.
BIOS-tick timings describe emulation only; electrical/card and physical 8088
qualification require hardware. DOS boot images and compilers are supplied
separately and are not included in the release archive.

`xcopy.py` runs genuine DOS XCOPY against a private FAT16 BIOS hard drive and
modeled SD. A 400 KiB file, nested/empty directories, 30 boundary-sized files,
read-only refusal, both write policies and cluster sizes 1/8 are exercised.
The HDD-only tree control captures the DOS5 empty-directory exit-code behavior.
Independent comparisons include bytes, sizes, timestamps and attributes; a
fresh boot copies the large file back to the HDD without SD writes, followed
by fsck. XCOPYT.C captures BIOS ticks/counter deltas before unmount's audit.
Licensed XCOPY/EXPAND are supplied on the external DOS media, not distributed.

`fast_native.py` is a private emulation-only probe of FASTIO.ASM, using genuine
DOS, a licensed Turbo C/TASM toolchain and the OTTER_MODEL_TEST adapter. It
checks independent CRC vectors, ABI/segments/DF/IF and odd copy guards, then
writes/restores a reserved scratch sector of its private image with three-access
burst settling. CRC/transport now use the restored production C code.
--mutations proves broken odd-tail copying and reversed copy direction are
caught. These raw probes are not included in KIT or intended for mounted hardware.
`rw_integration.py --profile settle` checks the same delay in the resident DOS
API flow. Model ports 335/336 are test instrumentation, absent on the ISA card.
`performance.py --label LABEL` counts real command traffic at SPC1/8 with exact
contents and fsck; host elapsed seconds do not measure assembly or DOS throughput.
Native XCOPY additionally reads under the writable mount before unmount/reboot.

Initialization failure modes in hardware.py inject a missing CMD0 response or
rejected CMD10 or a corrupt CID packet CRC. validate.py runs all three with
write readback enabled and disabled;
installation, /STATUS, failed /MOUNT and offline HWRT /INFO must preserve the
same SD evidence and leave the entire card image unchanged. A count-based
settling model cannot reproduce every elapsed-time regression on ISA hardware.

FAT16 regressions are in test_fat16.py and test_fat16_redirector.py; the fixture
builder fat16_fixture.py produces fixed-root FAT16 without importing Navigator.
The host runner merges both formats' production-code coverage while keeping
library outputs separate, so repeated compilations cannot overwrite loaded
coverage notes. test_large_image.py independently checks the 500 MiB FAT16
geometry and all original read patterns. After full main-kit qualification,
large_kits.py builds/qualifies both 500 MiB kits under the supplied real DOS
kernels; see docs/FAT16_IMAGE.md for the reproducible command.

Public release safety is exercised by test_release.py: exact floppy allowlists,
empty FAT16/FAT32 images, mirrors, backups/FSInfo, geometry, ZIP integrity and
version/tag consistency. release_integration.py boots real DOS with the public
floppy binary and an empty public SD image, creates/copies a file, unloads,
then verifies persistence on a fresh read-only boot. Public image tests need
no authorization marker or hardware tester. These probes are developer-only.

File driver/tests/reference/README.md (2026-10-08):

# Host regression references

These historical transport/diagnostic/filesystem sources preserve the hard-won
CRC-rejection, recovery and card-behavior regressions. WSD/WFS/WTEST/HOSTIO are
compiled only into host test libraries by test_write.py. SD.C/SDCMDS.ASM are
exercised by the independent native SDPROBE. Neither set is a public driver or
hardware utility, and no build/package target produces an old executable.
The only public DOS programs are OTTERSD.EXE and HWRT.EXE.

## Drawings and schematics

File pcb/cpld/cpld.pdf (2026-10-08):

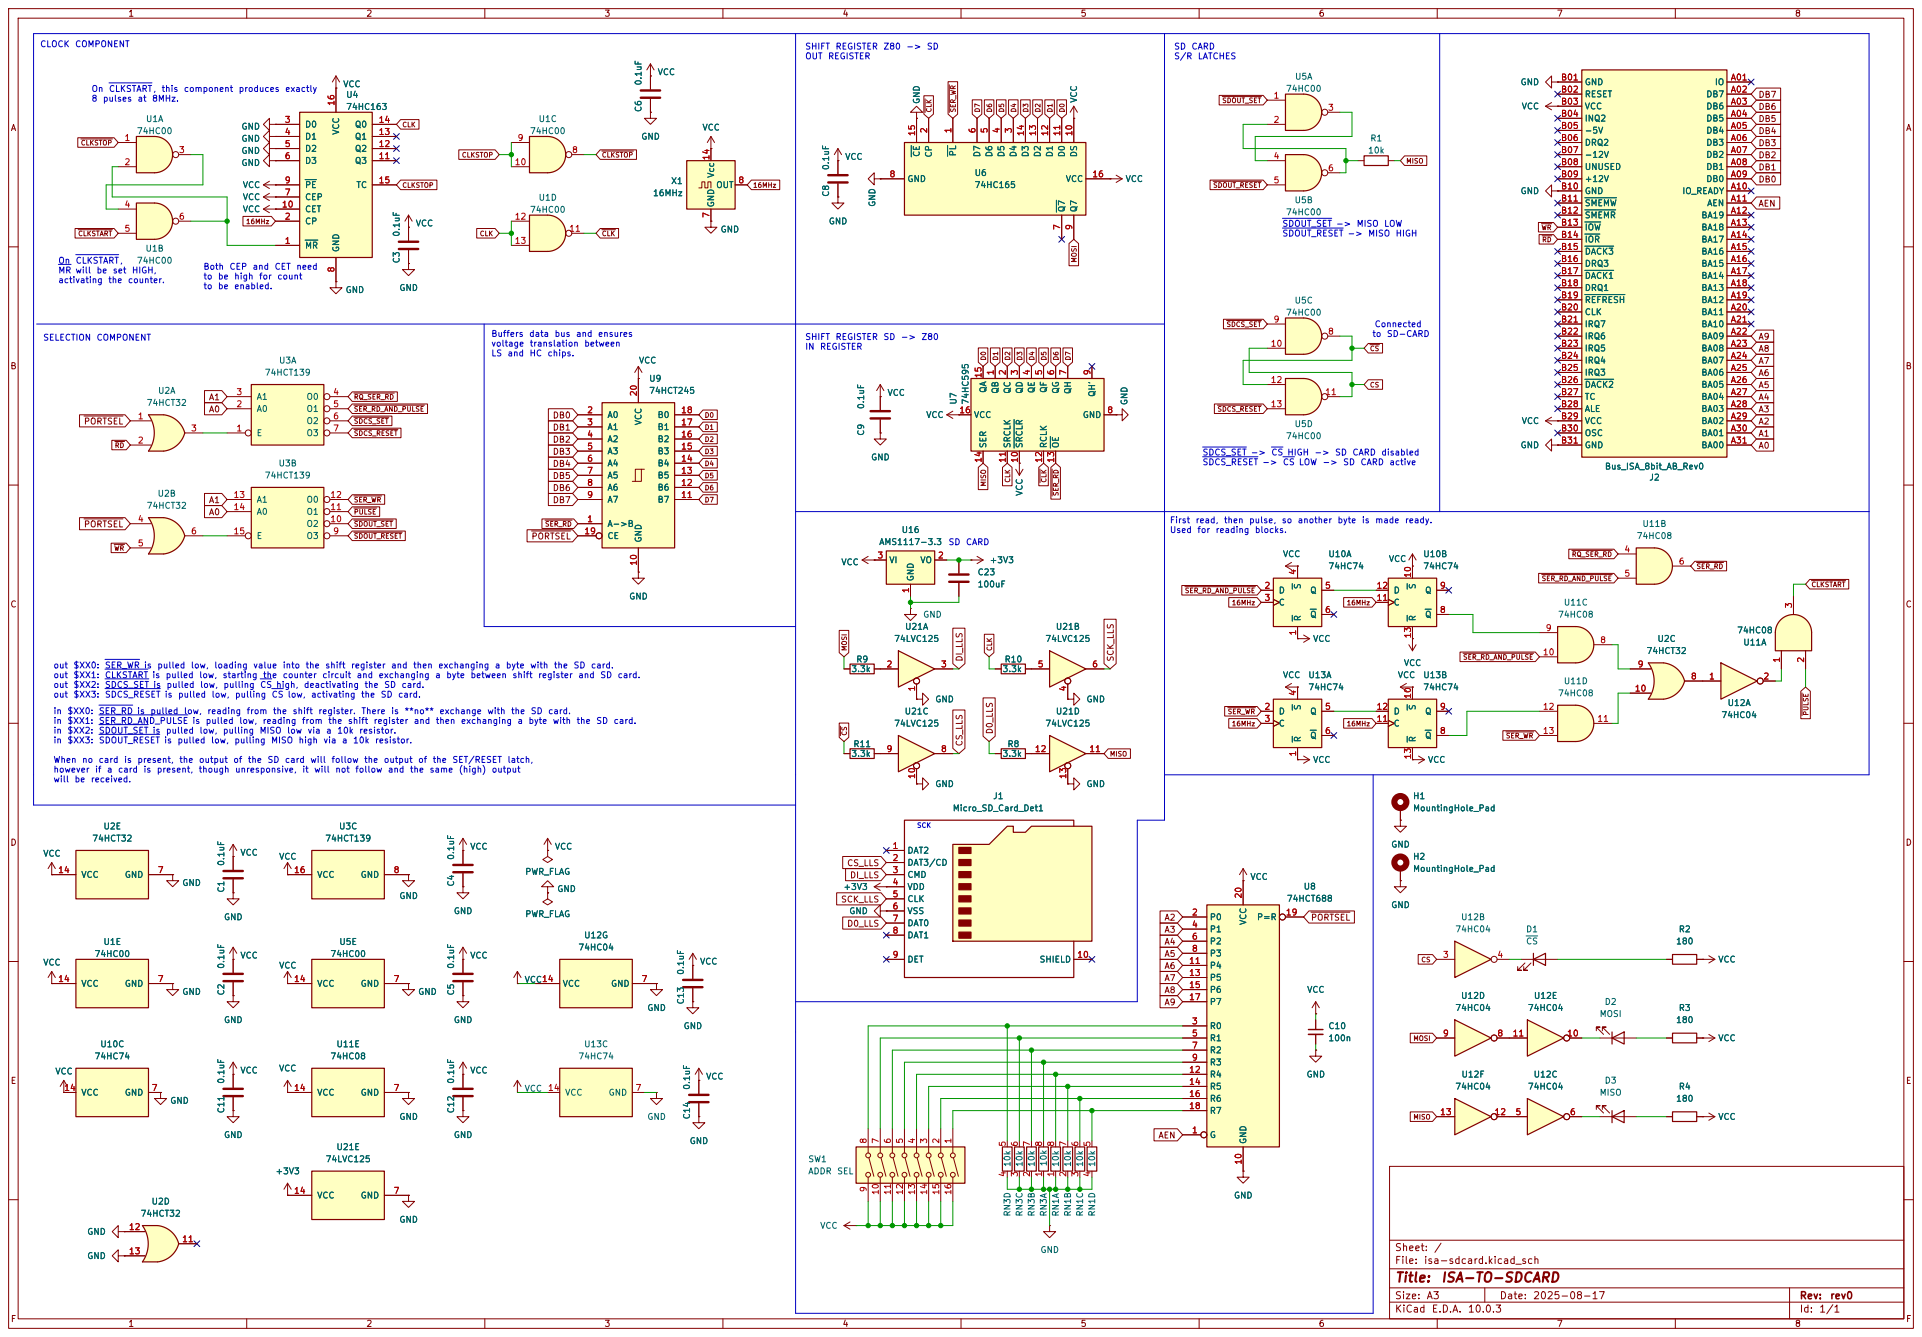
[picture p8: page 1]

7 OUT 8 Vcc 14 GND GND U6

to be high for count
to be enabled.

7 GND 8 QH' 9 SRCLR 10 SRCLK 11 RCLK 12 OE 13 SER 14 QA 15

74HCT245 GND

VCC VI 3 U16 U16 AMS1117-3.3 SD CARD 3.3k 5 U21B 6 U21B 74LVC125 74LVC125 74LVC125GND 74LVC125 | 6 U11B 74HC08

in $XX0: SER_RD is pulled low, reading from the shift register. There is **no** exchange with the SD card.
in $XX1: SER_RD_AND_PULSE is pulled low, reading from the shift register and then exchanging a byte with the SD card.
in $XX2: SDOUT_SET is pulled low, pulling MISO low via a 10k resistor.
in $XX3: SDOUT_RESET is pulled low, pulling MISO high via a 10k resistor. When no card is present, the output of the SD card will follow the output of the SET/RESET latch, however if a card is present, though unresponsive, it will not follow and the same (high) output will be received.

Sheet: /
File: isa-sdcard.kicad_sch
Title: ISA-TO-SDCARD

Size: A3 | Rev: rev0
KiCad E.D.A. 10.0.3 | Id: 1/1 | F Date: 2025-08-17

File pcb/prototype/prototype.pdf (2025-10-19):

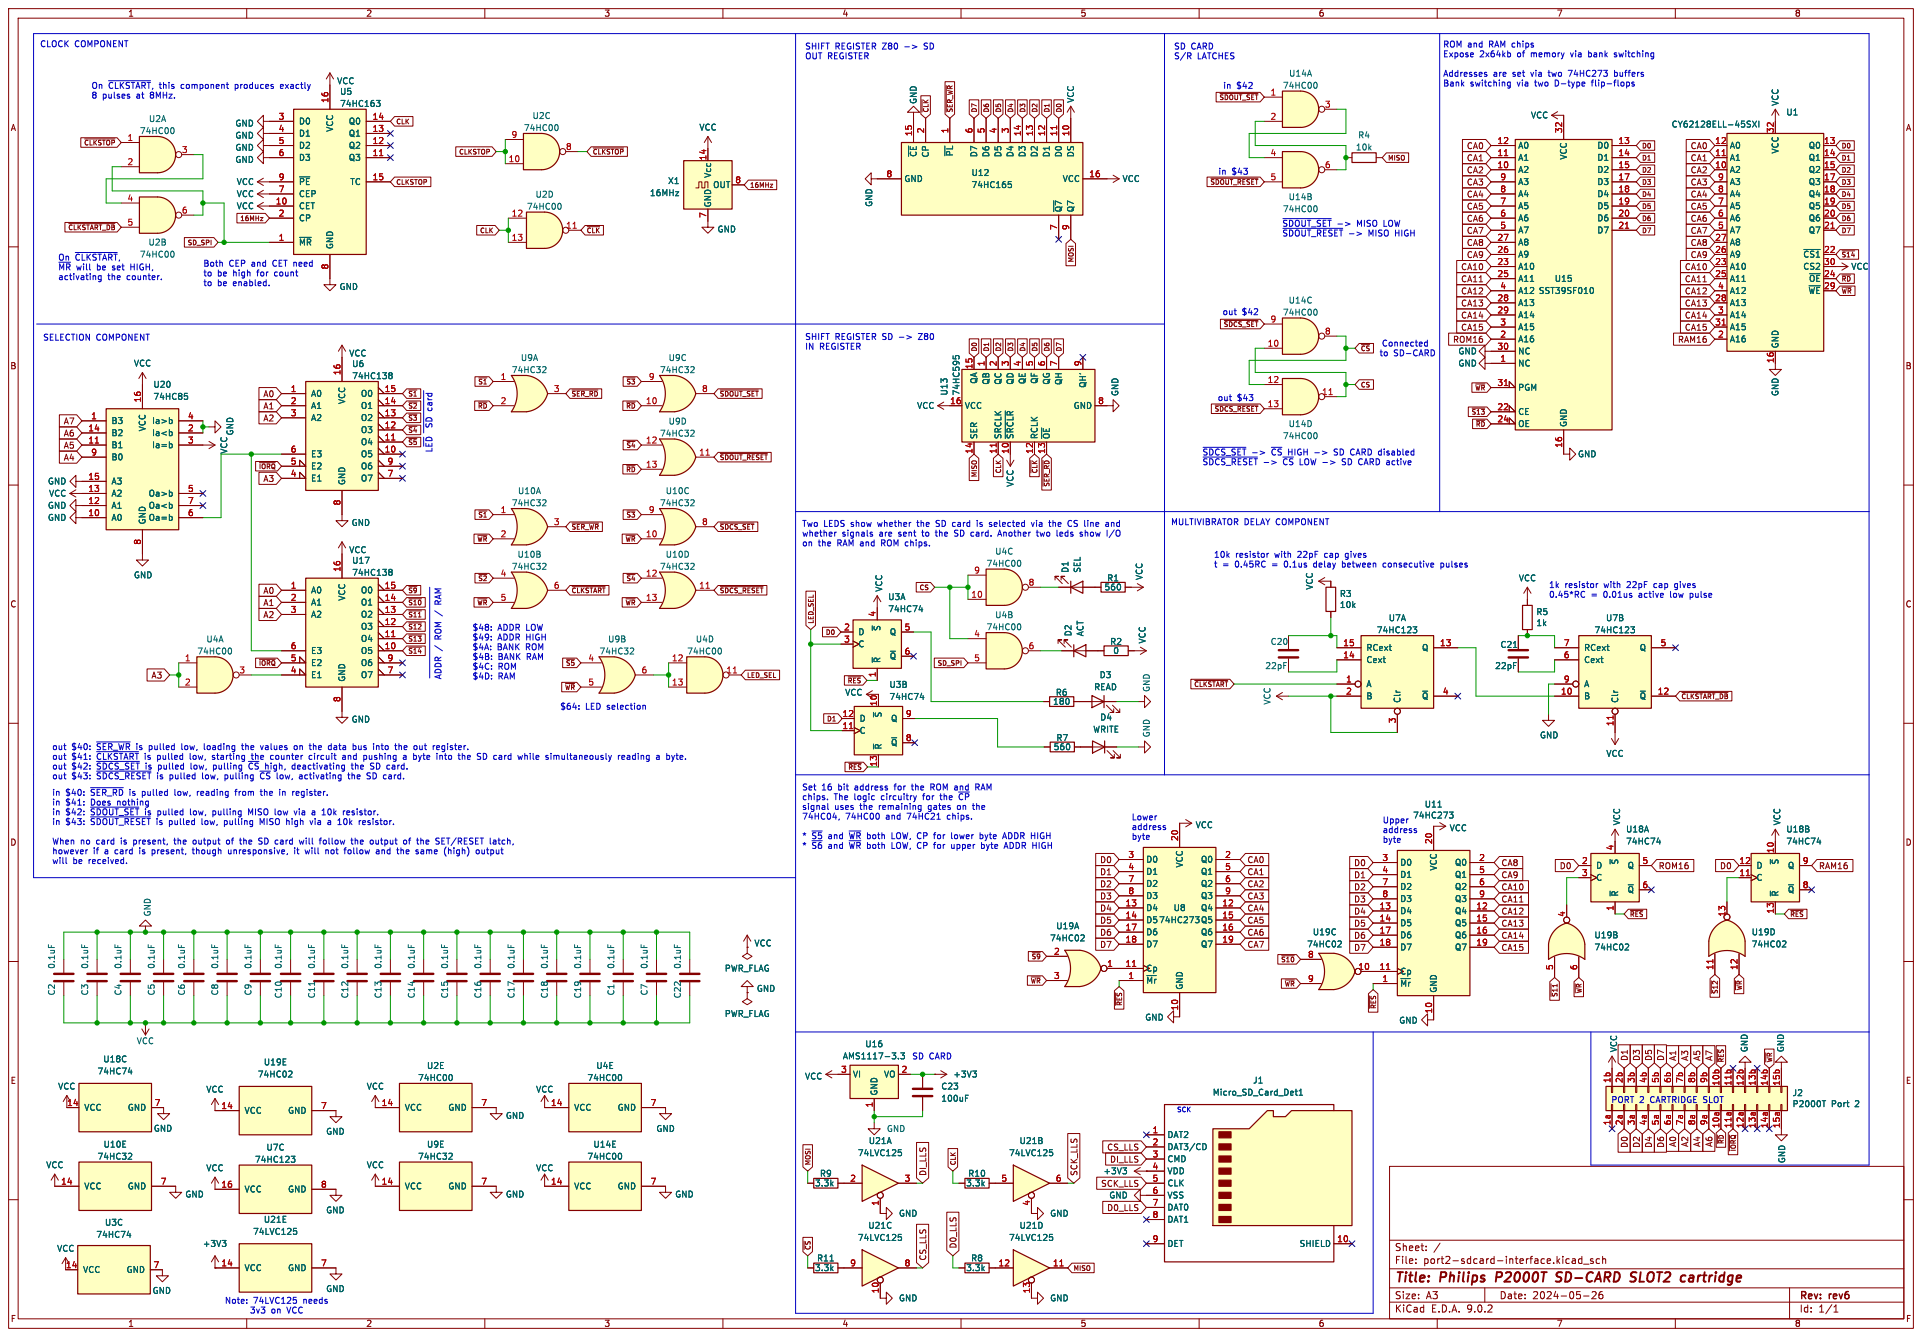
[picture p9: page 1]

8 O0 15 O1 14 O2 13 O3 12 O4 11 O5 10 O6 9 O7 7 VCC VCCGND GND GND GND GND GND

$64: LED selection On ~{CLKSTART},

Both CEP and CET need
to be high for count

MULTIVIBRATOR DELAY COMPONENT Set 16 bit address for the ROM and RAM

on the RAM and ROM chips.

in $40: ~{SER_RD}is pulled low, reading from the in register.
in $41: Does nothing

74HC04, 74HC00 and 74HC21 chips. * ~{S5}and ~{WR}both LOW, CP for lower byte ADDR HIGH

* ~{S6}and ~{WR}both LOW, CP for upper byte ADDR HIGH

Id: 1/1 Title: Philips P2000T SD-CARD SLOT2 cartridge

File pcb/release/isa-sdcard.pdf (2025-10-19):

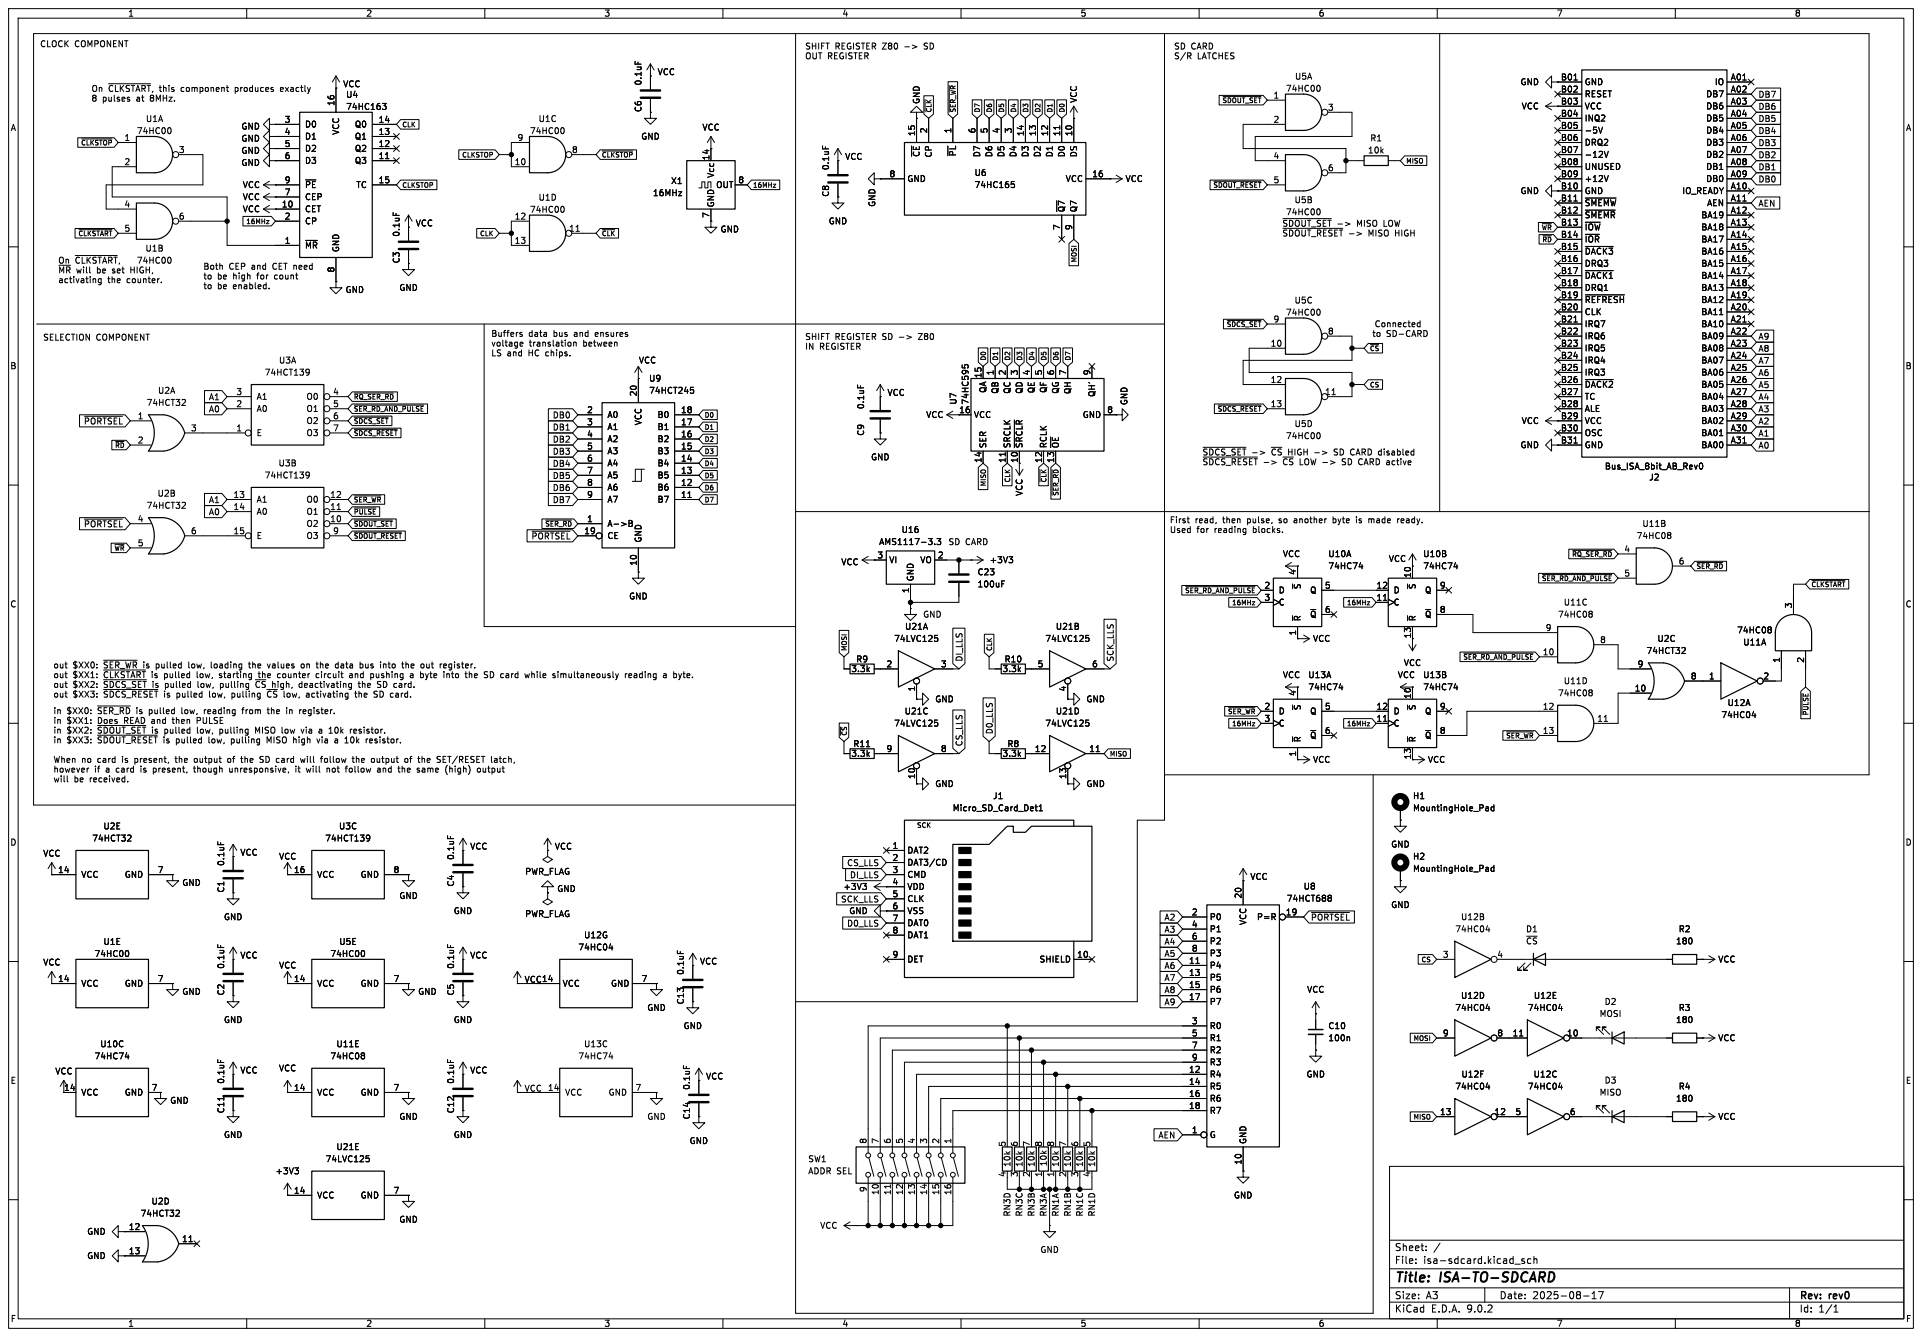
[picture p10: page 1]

1 101112131415169 SW1 ADDR SEL GND GND DS 10 D0 11 D1 12 D2 13 D3 14 D4

VCC
-12V B07 UNUSED B08 +12V B09 GND B10 ~{SMEMW} B11 ~{SMEMR} B12 ~{IOW} B13 ~{IOR} B14 ~{DACK3} B15 DRQ3 B16 ~{DACK1} B17 DRQ1 B18 ~{REFRESH} B19 CLK B20

to be high for count

1 VO 2 GND C9 0.1uF VCC U7 74HC595 SER 14 SRCLK 11 ~{SRCLR} 10 RCLK 12 ~{OE} 13 VCC 16 GND 8 QA 15 QB

in $XX0: ~{SER_RD}is pulled low, reading from the in register.
in $XX1: Does READ and then PULSE

Id: 1/1 Title: ISA-TO-SDCARD

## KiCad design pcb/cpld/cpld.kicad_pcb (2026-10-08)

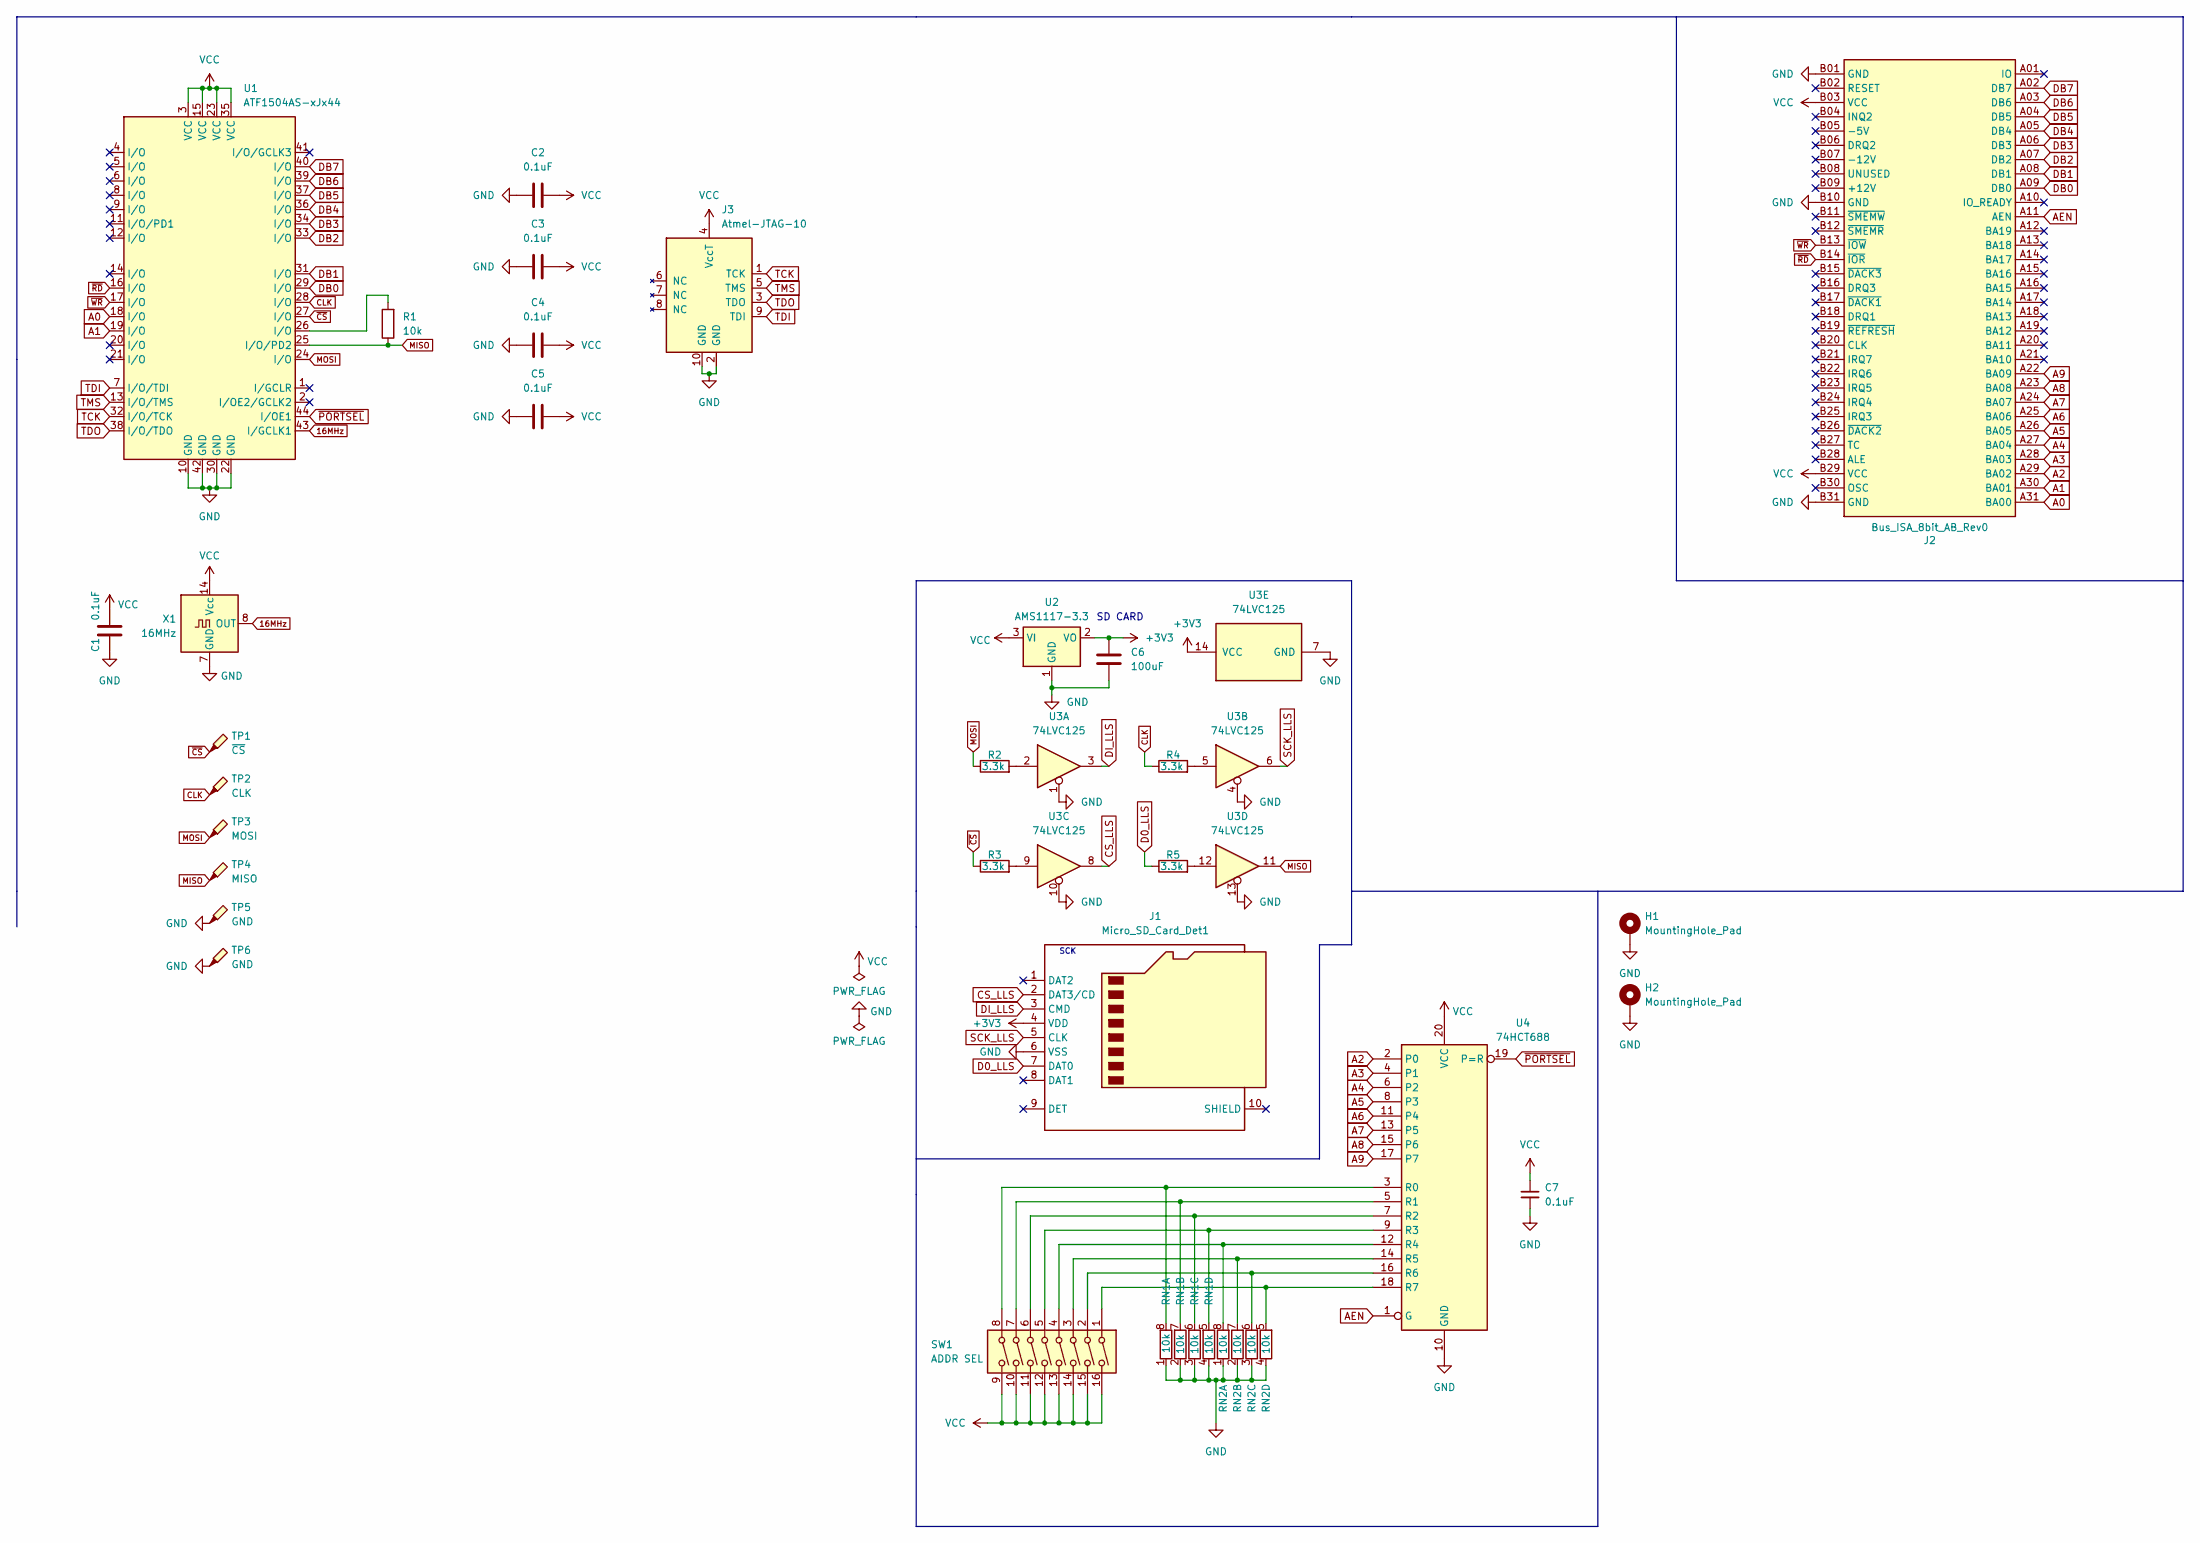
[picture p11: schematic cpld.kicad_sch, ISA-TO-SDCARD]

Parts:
C1, C7: 0.1uF; C_0805_2012Metric; LCSC C126469
C2, C3, C4, C5: 0.1uF; C_0805_2012Metric
C6: 100uF; C_1206_3216Metric_Pad1.33x1.80mm_HandSolder; LCSC C309030
H1, H2: MountingHole_Pad; MountingHole_3.2mm_M3_DIN965_Pad_TopBottom
J1: Micro_SD_Card_Det1; CONN9_MSD-1_CUD; LCSC C381082
J2: Bus_ISA_8bit_AB_Rev0; ISA_CARD_EDGE_CONNECTOR_8BIT_Rev1
J3: Atmel-JTAG-10; IDC-Header_2x05_P2.54mm_Vertical
R1: 10k; R_0805_2012Metric; LCSC C5159708
R2, R3, R4, R5: 3.3k; R_0805_2012Metric_Pad1.20x1.40mm_HandSolder; LCSC C407459
RN1, RN2: 10k; R_Array_Convex_4x0612; LCSC C29718
SW1: ADDR SEL; SW_DIP_SPSTx08_Slide_9.78x22.5mm_W7.62mm_P2.54mm
TP1: ~{CS}; TestPoint_Loop_D2.54mm_Drill1.5mm_Beaded
TP2: CLK; TestPoint_Loop_D2.54mm_Drill1.5mm_Beaded
TP3: MOSI; TestPoint_Loop_D2.54mm_Drill1.5mm_Beaded
TP4: MISO; TestPoint_Loop_D2.54mm_Drill1.5mm_Beaded
TP5, TP6: GND; TestPoint_Loop_D2.54mm_Drill1.5mm_Beaded
U1: ATF1504AS-xJx44; PLCC-44_THT-Socket
U2: AMS1117-3.3; SOT-223-3_TabPin2; LCSC C5346136
U3: 74LVC125; TSSOP-14_4.4x5mm_P0.65mm; LCSC C7494906
U4: 74HCT688; SOIC-20W_7.5x12.8mm_P1.27mm; LCSC C2649422
X1: 16MHz; Oscillator_DIP-14

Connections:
16MHz: U1.43 (I/GCLK1), X1.8 (OUT)
+3V3: C6.1, J1.4 (VDD), U2.2 (VO), U3.14 (VCC)
A0: J2.A31 (BA00), U1.18 (I/O)
A1: J2.A30 (BA01), U1.19 (I/O)
A2: J2.A29 (BA02), U4.2 (P0)
A3: J2.A28 (BA03), U4.4 (P1)
A4: J2.A27 (BA04), U4.6 (P2)
A5: J2.A26 (BA05), U4.8 (P3)
A6: J2.A25 (BA06), U4.11 (P4)
A7: J2.A24 (BA07), U4.13 (P5)
A8: J2.A23 (BA08), U4.15 (P6)
A9: J2.A22 (BA09), U4.17 (P7)
AEN: J2.A11 (AEN), U4.1 (G)
CLK: R4.1, TP2.1 (1_1), U1.28 (I/O)
CS_LLS: J1.2 (DAT3/CD), U3.8
D0_LLS: J1.7 (DAT0), R5.1
DB0: J2.A09 (DB0), U1.29 (I/O)
DB1: J2.A08 (DB1), U1.31 (I/O)
DB2: J2.A07 (DB2), U1.33 (I/O)
DB3: J2.A06 (DB3), U1.34 (I/O)
DB4: J2.A05 (DB4), U1.36 (I/O)
DB5: J2.A04 (DB5), U1.37 (I/O)
DB6: J2.A03 (DB6), U1.39 (I/O)
DB7: J2.A02 (DB7), U1.40 (I/O)
DI_LLS: J1.3 (CMD), U3.3
GND: C1.1, C2.2, C3.2, C4.2, C5.2, C6.2, C7.2, H1.1 (1_1), H2.1 (1_1), J1.6 (VSS), J2.B01 (GND), J2.B10 (GND), J2.B31 (GND), J3.2 (GND), J3.10 (GND), RN1.1 (R1.1), RN1.2 (R2.1), RN1.3 (R3.1), RN1.4 (R4.1), RN2.1 (R1.1), RN2.2 (R2.1), RN2.3 (R3.1), RN2.4 (R4.1), TP5.1 (1_1), TP6.1 (1_1), U1.10 (GND), U1.22 (GND), U1.30 (GND), U1.42 (GND), U2.1 (GND), U3.1, U3.4, U3.7 (GND), U3.10, U3.13, U4.10 (GND), X1.7 (GND)
MISO: R1.1, TP4.1 (1_1), U1.25 (I/O/PD2), U3.11
MOSI: R2.1, TP3.1 (1_1), U1.24 (I/O)
unnamed: R1.2, U1.26 (I/O)
unnamed: R2.2, U3.2
unnamed: R3.2, U3.9
unnamed: R4.2, U3.5
unnamed: R5.2, U3.12
unnamed: RN1.8 (R1.2), SW1.8, U4.3 (R0)
unnamed: RN1.7 (R2.2), SW1.7, U4.5 (R1)
unnamed: RN1.6 (R3.2), SW1.6, U4.7 (R2)
unnamed: RN1.5 (R4.2), SW1.5, U4.9 (R3)
unnamed: RN2.8 (R1.2), SW1.4, U4.12 (R4)
unnamed: RN2.7 (R2.2), SW1.3, U4.14 (R5)
unnamed: RN2.6 (R3.2), SW1.2, U4.16 (R6)
unnamed: RN2.5 (R4.2), SW1.1, U4.18 (R7)
SCK_LLS: J1.5 (CLK), U3.6
TCK: J3.1 (TCK), U1.32 (I/O/TCK)
TDI: J3.9 (TDI), U1.7 (I/O/TDI)
TDO: J3.3 (TDO), U1.38 (I/O/TDO)
TMS: J3.5 (TMS), U1.13 (I/O/TMS)
VCC: C1.2, C2.1, C3.1, C4.1, C5.1, C7.1, J2.B03 (VCC), J2.B29 (VCC), J3.4 (VccT), SW1.9, SW1.10, SW1.11, SW1.12, SW1.13, SW1.14, SW1.15, SW1.16, U1.3 (VCC), U1.15 (VCC), U1.23 (VCC), U1.35 (VCC), U2.3 (VI), U4.20 (VCC), X1.14 (Vcc)
~CS: R3.1, TP1.1 (1_1), U1.27 (I/O)
~PORTSEL: U1.44 (I/OE1), U4.19 (P=R)
~RD: J2.B14 (~IOR), U1.16 (I/O)
~WR: J2.B13 (~IOW), U1.17 (I/O)

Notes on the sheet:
SCK
SD CARD

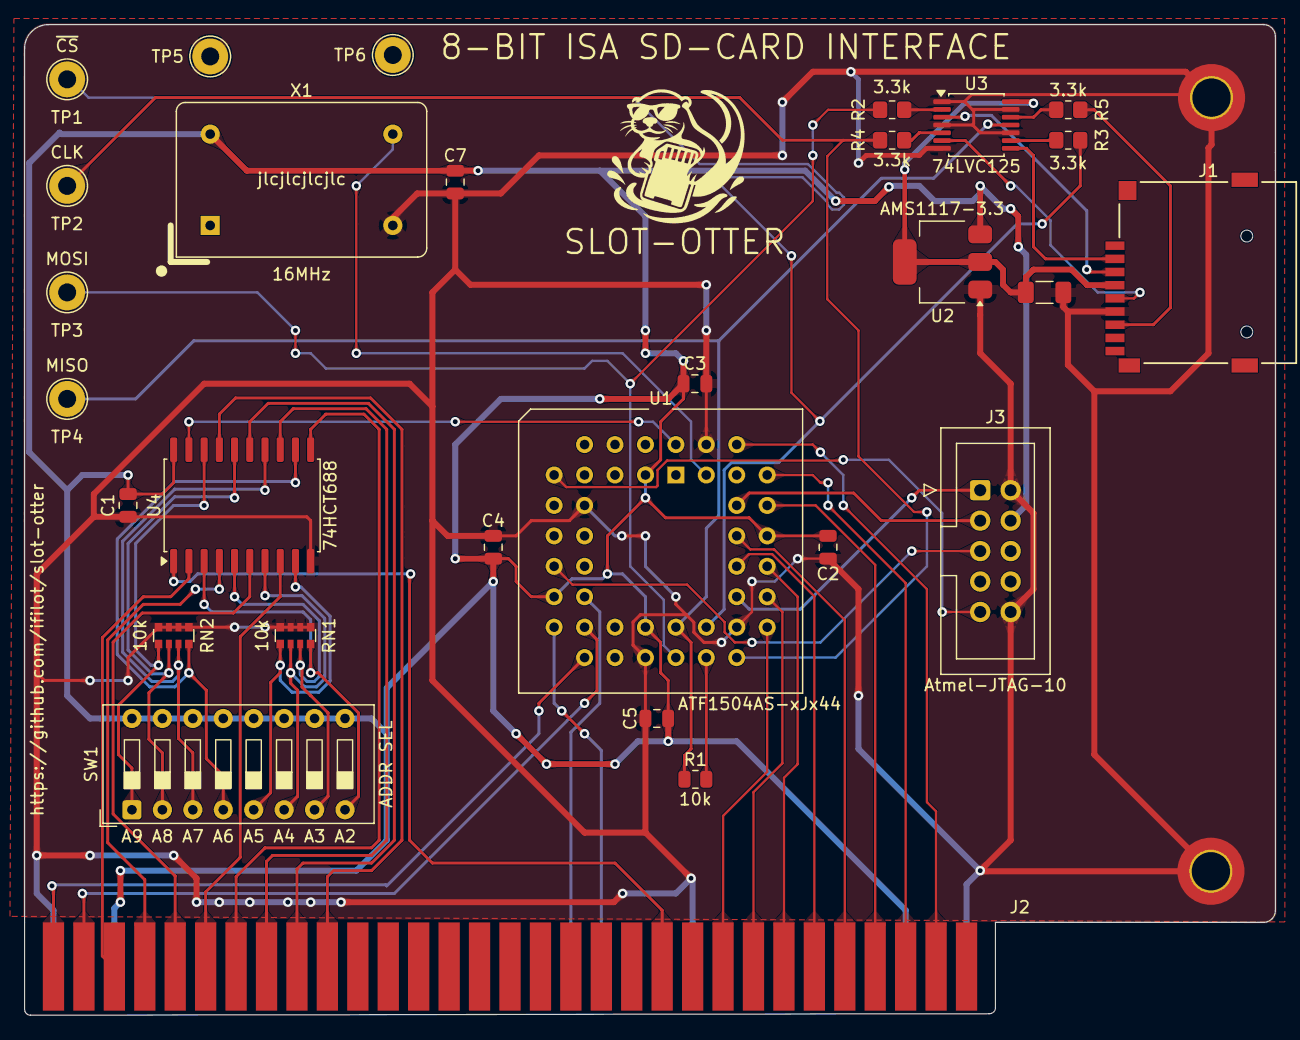
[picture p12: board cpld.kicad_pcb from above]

Board: 2 copper layers, 104.4 x 82.7 mm, 31 parts (0 on the bottom side), 51 nets.

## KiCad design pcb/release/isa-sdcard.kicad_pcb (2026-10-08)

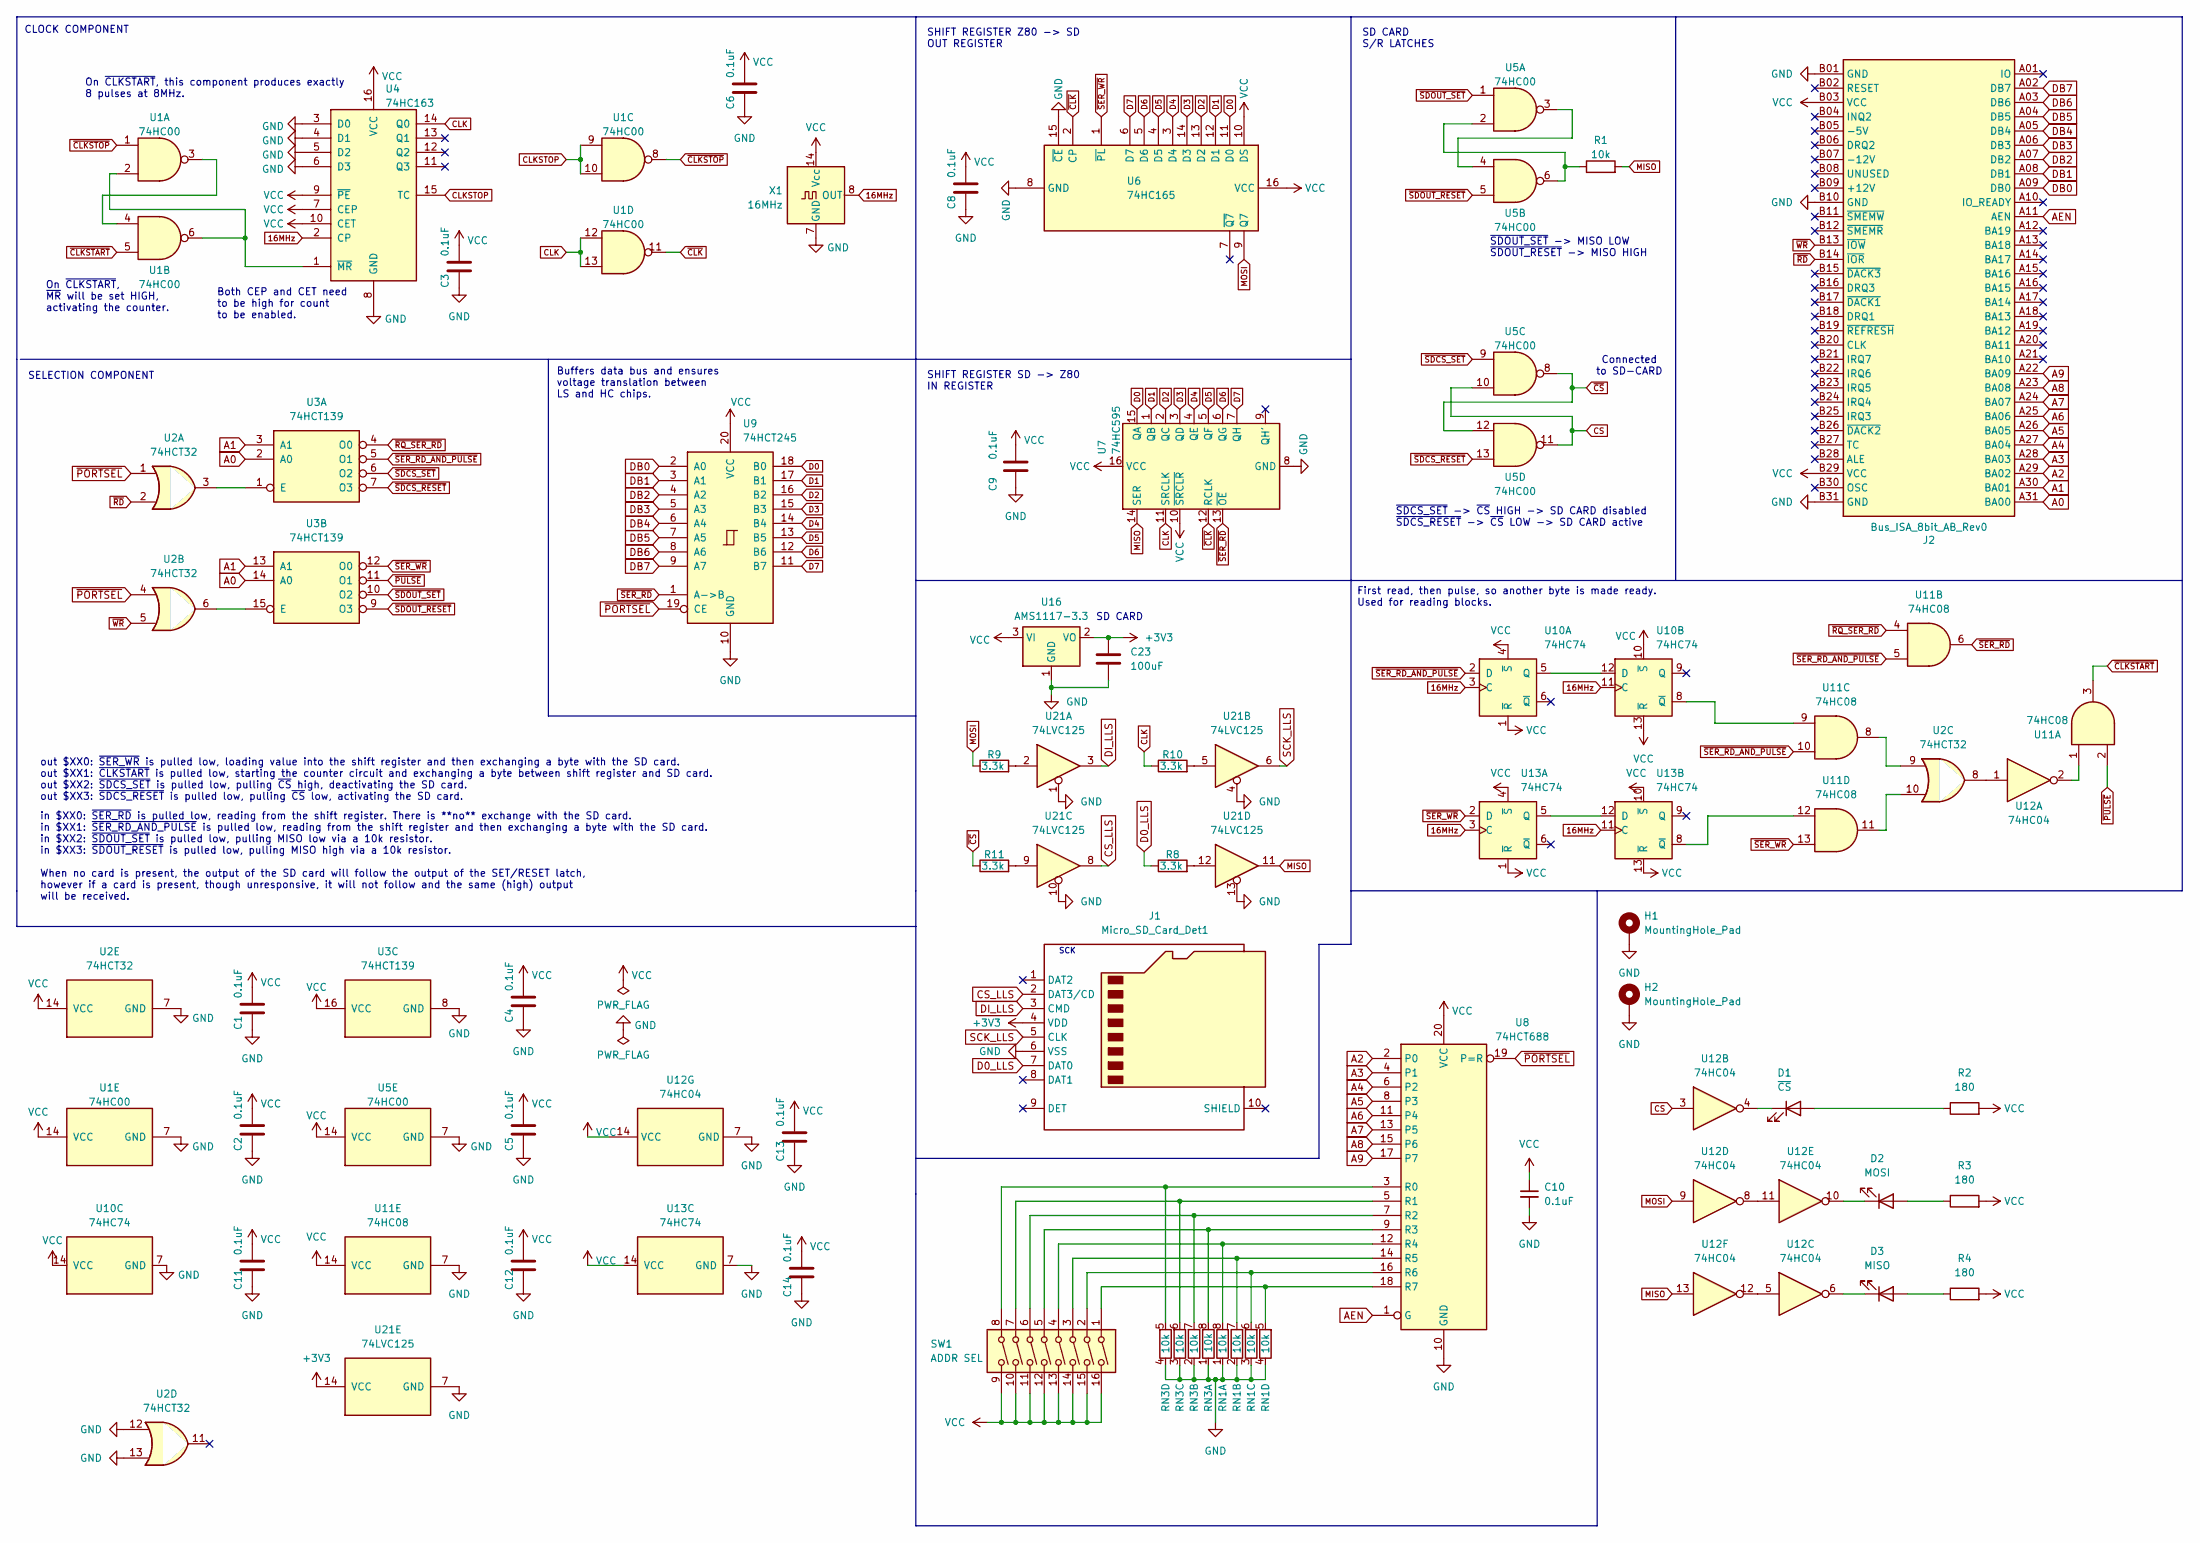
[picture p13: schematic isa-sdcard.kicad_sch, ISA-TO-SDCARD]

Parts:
C1, C2, C3, C4, C5, C6, C8, C9, C10, C11, C12, C13, C14: 0.1uF; C_0805_2012Metric; LCSC C126469
C23: 100uF; C_1206_3216Metric_Pad1.33x1.80mm_HandSolder; LCSC C309030
D1: ~{CS}; LED_0805_2012Metric; LCSC C84256
D2: MOSI; LED_0805_2012Metric; LCSC C84256
D3: MISO; LED_0805_2012Metric; LCSC C84256
H1, H2: MountingHole_Pad; MountingHole_3.2mm_M3_DIN965_Pad_TopBottom
J1: Micro_SD_Card_Det1; CONN9_MSD-1_CUD; LCSC C381082
J2: Bus_ISA_8bit_AB_Rev0; ISA_CARD_EDGE_CONNECTOR_8BIT_Rev1
R1: 10k; R_0805_2012Metric; LCSC C5159708
R2, R3, R4: 180; R_0805_2012Metric; LCSC C17540
R8, R9, R10, R11: 3.3k; R_0805_2012Metric_Pad1.20x1.40mm_HandSolder; LCSC C407459
RN1, RN3: 10k; R_Array_Convex_4x0612; LCSC C29718
SW1: ADDR SEL; SW_DIP_SPSTx08_Slide_9.78x22.5mm_W7.62mm_P2.54mm
U1, U5: 74HC00; SOIC-14_3.9x8.7mm_P1.27mm; LCSC C699445
U2: 74HCT32; SOIC-14_3.9x8.7mm_P1.27mm; LCSC C5985
U3: 74HCT139; SOIC-16_3.9x9.9mm_P1.27mm; LCSC C545677
U4: 74HC163; SOIC-16_3.9x9.9mm_P1.27mm; LCSC C338758
U6: 74HC165; SOIC-16_3.9x9.9mm_P1.27mm; LCSC C5613
U7: 74HC595; SOIC-16_3.9x9.9mm_P1.27mm; LCSC C5947
U8: 74HCT688; SOIC-20W_7.5x12.8mm_P1.27mm; LCSC C2649422
U9: 74HCT245; SOIC-20W_7.5x12.8mm_P1.27mm; LCSC C5979
U10, U13: 74HC74; SOIC-14_3.9x8.7mm_P1.27mm; LCSC C6762
U11: 74HC08; SOIC-14_3.9x8.7mm_P1.27mm; LCSC C5593
U12: 74HC04; SOIC-14_3.9x8.7mm_P1.27mm; LCSC C5590
U16: AMS1117-3.3; SOT-223-3_TabPin2; LCSC C5346136
U21: 74LVC125; TSSOP-14_4.4x5mm_P0.65mm; LCSC C7494906
X1: 16MHz; Oscillator_DIP-14

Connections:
16MHz: U4.2 (CP), U10.3 (C), U10.11 (C), U13.3 (C), U13.11 (C), X1.8 (OUT)
+3V3: C23.1, J1.4 (VDD), U16.2 (VO), U21.14 (VCC)
A0: J2.A31 (BA00), U3.2 (A0), U3.14 (A0)
A1: J2.A30 (BA01), U3.3 (A1), U3.13 (A1)
A2: J2.A29 (BA02), U8.2 (P0)
A3: J2.A28 (BA03), U8.4 (P1)
A4: J2.A27 (BA04), U8.6 (P2)
A5: J2.A26 (BA05), U8.8 (P3)
A6: J2.A25 (BA06), U8.11 (P4)
A7: J2.A24 (BA07), U8.13 (P5)
A8: J2.A23 (BA08), U8.15 (P6)
A9: J2.A22 (BA09), U8.17 (P7)
AEN: J2.A11 (AEN), U8.1 (G)
CLK: R10.1, U1.12, U1.13, U4.14 (Q0), U7.11 (SRCLK)
CLKSTOP: U1.9, U1.10, U4.15 (TC)
CS: U5.10, U5.11, U12.3
CS_LLS: J1.2 (DAT3/CD), U21.8
D0: U6.11 (D0), U7.15 (QA), U9.18 (B0)
D0_LLS: J1.7 (DAT0), R8.1
D1: U6.12 (D1), U7.1 (QB), U9.17 (B1)
D2: U6.13 (D2), U7.2 (QC), U9.16 (B2)
D3: U6.14 (D3), U7.3 (QD), U9.15 (B3)
D4: U6.3 (D4), U7.4 (QE), U9.14 (B4)
D5: U6.4 (D5), U7.5 (QF), U9.13 (B5)
D6: U6.5 (D6), U7.6 (QG), U9.12 (B6)
D7: U6.6 (D7), U7.7 (QH), U9.11 (B7)
DB0: J2.A09 (DB0), U9.2 (A0)
DB1: J2.A08 (DB1), U9.3 (A1)
DB2: J2.A07 (DB2), U9.4 (A2)
DB3: J2.A06 (DB3), U9.5 (A3)
DB4: J2.A05 (DB4), U9.6 (A4)
DB5: J2.A04 (DB5), U9.7 (A5)
DB6: J2.A03 (DB6), U9.8 (A6)
DB7: J2.A02 (DB7), U9.9 (A7)
DI_LLS: J1.3 (CMD), U21.3
GND: C1.1, C2.1, C3.1, C4.1, C5.1, C6.1, C8.1, C9.1, C10.2, C11.1, C12.1, C13.1, C14.1, C23.2, H1.1, H2.1, J1.6 (VSS), J2.B01 (GND), J2.B10 (GND), J2.B31 (GND), RN1.1 (R1.1), RN1.2 (R2.1), RN1.3 (R3.1), RN1.4 (R4.1), RN3.1 (R1.1), RN3.2 (R2.1), RN3.3 (R3.1), RN3.4 (R4.1), U1.7 (GND), U2.7 (GND), U2.12, U2.13, U3.8 (GND), U4.3 (D0), U4.4 (D1), U4.5 (D2), U4.6 (D3), U4.8 (GND), U5.7 (GND), U6.8 (GND), U6.15 (~CE), U7.8 (GND), U8.10 (GND), U9.10 (GND), U10.7 (GND), U11.7 (GND), U12.7 (GND), U13.7 (GND), U16.1 (GND), U21.1, U21.4, U21.7 (GND), U21.10, U21.13, X1.7 (GND)
MISO: R1.2, U7.14 (SER), U12.13, U21.11
MOSI: R9.1, U6.9 (Q7), U12.9
unnamed: D1.2 (A), R2.1
unnamed: D1.1 (K), U12.4
unnamed: D2.2 (A), R3.1
unnamed: D2.1 (K), U12.10
unnamed: D3.2 (A), R4.1
unnamed: D3.1 (K), U12.6
unnamed: R1.1, U5.2, U5.6
unnamed: R8.2, U21.12
unnamed: R9.2, U21.2
unnamed: R10.2, U21.5
unnamed: R11.2, U21.9
unnamed: RN1.8 (R1.2), SW1.4, U8.12 (R4)
unnamed: RN1.7 (R2.2), SW1.3, U8.14 (R5)
unnamed: RN1.6 (R3.2), SW1.2, U8.16 (R6)
unnamed: RN1.5 (R4.2), SW1.1, U8.18 (R7)
unnamed: RN3.8 (R1.2), SW1.5, U8.9 (R3)
unnamed: RN3.7 (R2.2), SW1.6, U8.7 (R2)
unnamed: RN3.6 (R3.2), SW1.7, U8.5 (R1)
unnamed: RN3.5 (R4.2), SW1.8, U8.3 (R0)
unnamed: U1.3, U1.4
unnamed: U2.3, U3.1 (E)
unnamed: U2.6, U3.15 (E)
unnamed: U1.2, U1.6, U4.1 (~MR)
unnamed: U5.3, U5.4
unnamed: U10.5 (Q), U10.12 (D)
unnamed: U10.8 (~Q), U11.9
unnamed: U11.1, U12.2
unnamed: U2.9, U11.8
unnamed: U2.10, U11.11
unnamed: U2.8, U12.1
unnamed: U12.8, U12.11
unnamed: U12.5, U12.12
unnamed: U13.5 (Q), U13.12 (D)
unnamed: U11.12, U13.8 (~Q)
SCK_LLS: J1.5 (CLK), U21.6
VCC: C1.2, C2.2, C3.2, C4.2, C5.2, C6.2, C8.2, C9.2, C10.1, C11.2, C12.2, C13.2, C14.2, J2.B03 (VCC), J2.B29 (VCC), R2.2, R3.2, R4.2, SW1.9, SW1.10, SW1.11, SW1.12, SW1.13, SW1.14, SW1.15, SW1.16, U1.14 (VCC), U2.14 (VCC), U3.16 (VCC), U4.7 (CEP), U4.9 (~PE), U4.10 (CET), U4.16 (VCC), U5.14 (VCC), U6.10 (DS), U6.16 (VCC), U7.10 (~SRCLR), U7.16 (VCC), U8.20 (VCC), U9.20 (VCC), U10.1 (~R), U10.4 (~S), U10.10 (~S), U10.13 (~R), U10.14 (VCC), U11.14 (VCC), U12.14 (VCC), U13.1 (~R), U13.4 (~S), U13.10 (~S), U13.13 (~R), U13.14 (VCC), U16.3 (VI), X1.14 (Vcc)
~CLKSTART: U1.5, U11.3
~CLKSTOP: U1.1, U1.8
~CLK: U1.11, U6.2 (CP), U7.12 (RCLK)
~CS: R11.1, U5.8, U5.12
~PORTSEL: U2.1, U2.4, U8.19 (P=R), U9.19 (CE)
~PULSE: U3.11 (O1), U11.2
~RD: J2.B14 (~IOR), U2.2
~RQ_SER_RD: U3.4 (O0), U11.4
~SDCS_RESET: U3.7 (O3), U5.13
~SDCS_SET: U3.6 (O2), U5.9
~SDOUT_RESET: U3.9 (O3), U5.5
~SDOUT_SET: U3.10 (O2), U5.1
~SER_RD_AND_PULSE: U3.5 (O1), U10.2 (D), U11.5, U11.10
~SER_RD: U7.13 (~OE), U9.1 (A->B), U11.6
~SER_WR: U3.12 (O0), U6.1 (~PL), U11.13, U13.2 (D)
~WR: J2.B13 (~IOW), U2.5

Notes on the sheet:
First read, then pulse, so another byte is made ready. Used for reading blocks.
SHIFT REGISTER SD -> Z80 IN REGISTER
SD CARD S/R LATCHES
out $XX0: ~{SER_WR} is pulled low, loading value into the shift register and then exchanging a byte with the SD card. out $XX1: ~{CLKSTART} is pulled low, starting the counter circuit and exchanging a byte between shift register and SD card. out $XX2: ~{SDCS_SET} is pulled low, pulling ~{CS} high, 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
On ~{CLKSTART}, this component produces exactly 8 pulses at 8MHz.
SCK
On ~{CLKSTART}, ~{MR} will be set HIGH, activating the counter.
in $XX0: ~{SER_RD} is pulled low, reading from the shift register. There is **no** exchange with the SD card. in $XX1: ~{SER_RD_AND_PULSE} is pulled low, reading from the shift register and then exchanging a byte with the SD card. in $XX2: ~{SDOUT_SET} is pulled low, pulling MISO low via a 10k resi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
Connected to SD-CARD
~{SDOUT_SET} -> MISO LOW ~{SDOUT_RESET} -> MISO HIGH
~{SDCS_SET} -> ~{CS} HIGH -> SD CARD disabled ~{SDCS_RESET} -> ~{CS} LOW -> SD CARD active
SELECTION COMPONENT
CLOCK COMPONENT
SD CARD
Buffers data bus and ensures voltage translation between LS and HC chips.
Both CEP and CET need to be high for count to be enabled.
SHIFT REGISTER Z80 -> SD OUT REGISTER

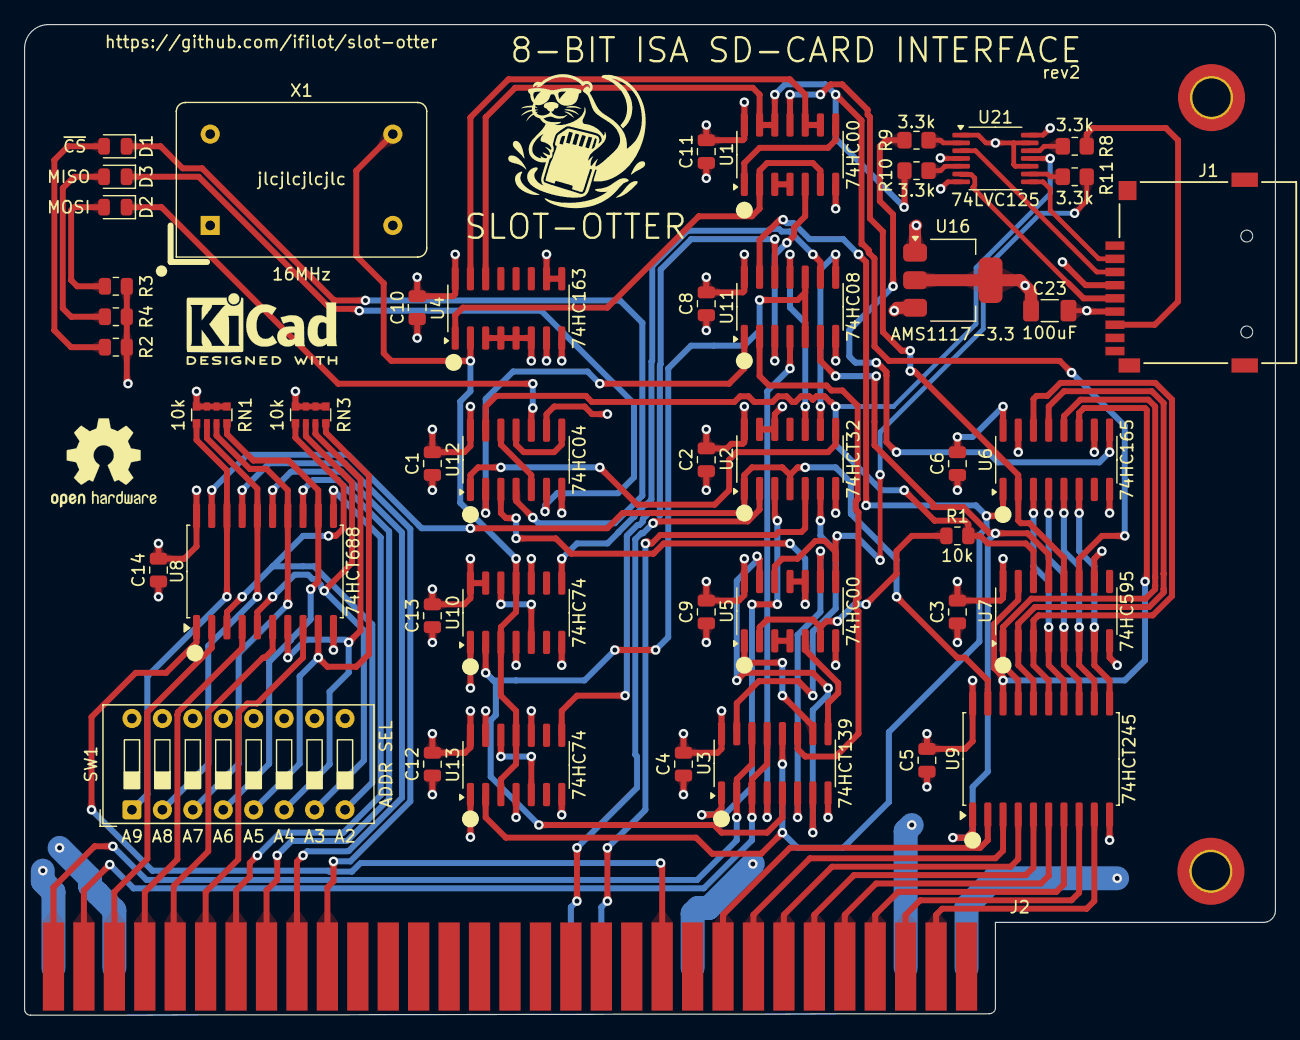
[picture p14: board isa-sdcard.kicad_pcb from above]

Board: 4 copper layers, 104.4 x 82.7 mm, 48 parts (0 on the bottom side), 90 nets.

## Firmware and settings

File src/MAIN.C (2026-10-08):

/* =====================================================================
 *  Project: SLOT-OTTER
 *  File:    MAIN.C
 *  Author:  Ivo Filot <ivo@ivofilot.nl>
 *
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
 *  You should have received a copy of the GNU General Public License
 *  along with this program.  If not, see <https://www.gnu.org/licenses/>.
 * ===================================================================== */

#include <stdio.h>
#include <dos.h>

#include "cfg.h"
#include "sd.h"
#include "fat32.h"
#include "helpers.h"
#include "hdnav.h"
#include "sdnav.h"
#include "help.h"
#include "settings.h"
#include "transfer.h"

#define STATE_MAIN_MENU 0
#define STATE_SD        1
#define STATE_HDNAV     2
#define STATE_EXIT      -1
#define CWDBUFLEN       256

int state_main_menu();
int state_sd();
int state_hdnav();
void init_fat();
int boot_sd_card();
int apply_settings_and_reinit();

static char cwd[CWDBUFLEN];

int main() {
    int state = STATE_SD;

    cfg_init(CFG_FILENAME);

    /* try to boot the sd card */
    if(boot_sd_card() != 0) {
        sddis(cfg_get_base_port());
        return -1;
    }

    /* store current working directory */
    getcwd(cwd, CWDBUFLEN);

    /* query display mode */
    display_mode = get_video_mode();

    /* initialize view */
    sdnav_init();
    disable_cursor();

    /* initialize navigation */
    hdnav_init();

    /* initialize SD card */
    init_fat();

    while(state != STATE_EXIT) {
        switch(state) {
            case STATE_MAIN_MENU:
                state = state_main_menu();
            break;
            case STATE_SD:
                state = state_sd();
            break;
            case STATE_HDNAV:
                state = state_hdnav();
            break;
            default:
                state = state_main_menu();
            break;
        }
    }

    /* disable SD card */
    sddis(cfg_get_base_port());

    /* close view and reset colors to MS-DOS default */
    window(1,1,80,25);
    textbackground(BLACK);
    textcolor(LIGHTGRAY);
    clrscr();

    /* restore starting cwd */
    chdir(cwd);

    /* restore cursor */
    enable_cursor();

    return 0;
}

/*
 * main menu state of the program
 */
int state_main_menu() {
    int c;
    while(1) {
        c = getch();
        if(c == 0) { /* special key */
            c = getch();
            switch(c) {
                case 0x3B:
                    help_show();
                break;
                case 0x42:
                    if(settings_show()) {
                        apply_settings_and_reinit();
                    }
                break;
                case 0x44:
                    return STATE_EXIT;
            }
        }
    }
}

/*
 * user is in SD navigation panel
 */
int state_sd() {
    unsigned char c;
    int fpos;
    const struct FAT32File* f;
    char filename[13];

    while(1) {
        c = getch();
        if(c == 0) {
            c = getch();
            switch(c) {
                case 0x3B:
                    help_show();
                    sdnav_display_commands();
                    sdnav_set_cursor();
                break;
                case 0x3C:
                    sdnav_create_folder();
                break;
                case 0x3E:
                    fpos = sdnav_get_cursor_pos();
                    f = fat32_get_file_entry(fpos);
                    sdnav_delete_entry(f);
                break;
                case 0x42:
                    if(settings_show()) {
                        apply_settings_and_reinit();
                        sdnav_display_commands();
                        sdnav_set_cursor();
                    }
                break;
                case 0x44:
                    return STATE_EXIT;
                case 0x49:
                    sdnav_move_cursor(-22);
                break;
                case 0x51:
                    sdnav_move_cursor(22);
                break;
            }
        }

        switch(c) {
            case 0x09:
                sdnav_remove_cursor();
                hdnav_set_cursor();
                hdnav_display_commands();
                return STATE_HDNAV;
            case 0x3D:
                fpos = sdnav_get_cursor_pos();
                f = fat32_get_file_entry(fpos);
                if(memcmp(f->basename, ".       ", 8) == 0 ||
                   memcmp(f->basename, "..      ", 8) == 0) {
                    break;
                }
                if(f->attrib & MASK_DIR) {
                    transfer_sd_folder_to_hd(f);
                } else {
                    build_dos_filename(f, filename);
                    transfer_sd_file_to_hd(f, filename);
                }
                hdnav_read_files();
                hdnav_print_files();
                hdnav_reset_cursor();
                hdnav_remove_cursor();
            break;
            case 0x50:
                sdnav_move_cursor(1);
            break;
            case 0x48:
                sdnav_move_cursor(-1);
            break;
            case 0x0D:
                fpos = sdnav_get_cursor_pos();
                f = fat32_get_file_entry(fpos);
                if(f->attrib & MASK_DIR) {
                    fat32_set_current_folder(f);
                    sdnav_print_files();
                    sdnav_reset_cursor();
                }
            break;
        }
    }
}

/*
 * user is in HD navigation panel
 */
int state_hdnav() {
    unsigned char c;
    int fpos;
    const struct HDNavFile* f;

    while(1) {
        c = getch();
        if(c == 0) {
            c = getch();
            switch(c) {
                case 0x3B:
                    help_show();
                    hdnav_display_commands();
                    hdnav_set_cursor();
                break;
                case 0x3C:
                    hdnav_create_folder();
                break;
                case 0x3D:
                    fpos = hdnav_get_cursor_pos();
                    f = hdnav_get_file_entry(fpos);
                    if(f->attrib & HDNAV_MASK_DIR) {
                        transfer_hd_folder_to_sd(f);
                        sdnav_print_files();
                        sdnav_reset_cursor();
                        sdnav_remove_cursor();
                    } else {
                        transfer_hd_file_to_sd_ui(f);
                        sdnav_print_files();
                        sdnav_reset_cursor();
                        sdnav_remove_cursor();
                    }
                break;
                case 0x3E:
                    fpos = hdnav_get_cursor_pos();
                    f = hdnav_get_file_entry(fpos);
                    hdnav_delete_entry(f);
                break;
                case 0x42:
                    if(settings_show()) {
                        apply_settings_and_reinit();
                        hdnav_display_commands();
                        hdnav_set_cursor();
                    }
                break;
                case 0x44:
                    return STATE_EXIT;
                case 0x49:
                    hdnav_move_cursor(-22);
                break;
                case 0x51:
                    hdnav_move_cursor(22);
                break;
            }
        }

        switch(c) {
            case 0x09:
                hdnav_remove_cursor();
                sdnav_set_cursor();
                sdnav_display_commands();
                return STATE_SD;
            case 0x50:
                hdnav_move_cursor(1);
            break;
            case 0x48:
                hdnav_move_cursor(-1);
            break;
            case 0x0D:
                fpos = hdnav_get_cursor_pos();
                f = hdnav_get_file_entry(fpos);
                if(f->attrib & HDNAV_MASK_DIR) {
                    hdnav_change_folder(f);
                    hdnav_read_files();
                    hdnav_print_files();
                    hdnav_reset_cursor();
                }
            break;
        }
    }
}

/*
 *  boot_sd_card - Try to open the SD card
 */
int boot_sd_card() {
    static unsigned char buf[514];
    int res = -1;
    unsigned attempts = 0;

    while(res != 0 && attempts < 10) {
        attempts++;
        printf("Trying to open SD card at base port 0x%X (%i)\n", cfg_get_base_port(), attempts);
        res = sd_boot();
        if(res != 0) {
            printf("Cannot open SD-card, exiting...\n");
            continue;
        }

        res = cmd17(cfg_get_base_port(), 0x00000000, buf);
        if(res != 0) {
            printf("Cannot read boot sector.\n");
            continue;
        }

        if(buf[510] != 0x55 || buf[511] != 0xAA) {
            printf("Cannot read boot sector pattern.\n");
            res = -1;
            continue;
        }
    }

    return res;
}

int apply_settings_and_reinit() {
    if(boot_sd_card() != 0) {
        return -1;
    }

    init_fat();
    hdnav_read_files();
    hdnav_print_files();
    hdnav_reset_cursor();
    hdnav_remove_cursor();

    return 0;
}

/*
 *  init_fat - Try to initialize the FAT32 system
 */
void init_fat() {
    fat32_open_partition();
    sdnav_print_volume_label(fat32_partition.volume_label);
    fat32_read_current_folder();
    sdnav_print_files();
    sdnav_reset_cursor();
}

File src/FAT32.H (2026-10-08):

/* =====================================================================
 *  Project: SLOT-OTTER
 *  File:    FAT32.H
 *  Author:  Ivo Filot <ivo@ivofilot.nl>
 *
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
 *  You should have received a copy of the GNU General Public License
 *  along with this program.  If not, see <https://www.gnu.org/licenses/>.
 * ===================================================================== */

#ifndef _FAT32_H
#define _FAT32_H

#include <stdio.h>
#include <time.h>

#include "fatstruc.h"
#include "sdcmds.h"
#include "cfg.h"

#define F32LLSZ  2048  	/* maximum linked list size */
#define F32MXFL  512  	/* maximum number of files in folder to parse */
#define F32MXDIR 256  	/* maximum number of folders that can be copied */
#define MAXPATH   80  	/* maximum number of characters in path */

#define MASK_DIR (1 << 4)
#define FILE_ENTRY 0
#define FOLDER_ENTRY 1

extern struct FAT32Partition fat32_partition;
extern struct FAT32File fat32_files[F32MXFL];
extern unsigned int fat32_nrfiles;

/**
 *  fat32_open_partition - Open FAT32 partition
 *
 *  Tries to open the first partition on the SD-CARD as a FAT32 partition.
 *  Sets the ROOT directory as the current directory.
 */
void fat32_open_partition();

/**
 *  fat32_print_partition_info - Print the current partition info
 *
 *  Prints relevant partition information.
 */
void fat32_print_partition_info();

/**
 *  fat32_read_current_folder - Read the currently active folder
 *
 *  Grabs all the files and folders present in the currently active folder
 *  and sorts them. The result will be stored in fat32_files which is an array
 *  of FAT32File structures. After reading, the files can be displayed on the 
 *  screen.
 */
void fat32_read_current_folder();

/**
 *  fat32_read_dir - Read a folder
 *
 *  Parameters:
 *      folder - Pointer to FAT32Folder struct
 *      buffer - Array of FAT32File objects to store results in
 *
 *  Reads the folder indicated by the FAT32Folder pointer and store all the
 *  files in the buffer. The buffer should be pre-allocated and is set to the
 *  maximum capacity. This function terminates early when the maximum number
 *  of files are being read.
 */
void fat32_read_dir(struct FAT32Folder* folder, struct FAT32File buffer[]);

/**
 *  fat32_set_current_folder - Set the current folder
 *
 *  Parameters:
 *      entry - FAT32File pointer
 *
 *  Using a FAT32File pointer, the current active folder is being set. After
 *  setting the folder, the folder is automatically being read and the buffer
 *  is populated. When the entry's cluster points to 0x00000000, it is
 *  automatically being recognized as the ROOT folder and set accordingly.
 */
void fat32_set_current_folder(const struct FAT32File* entry);

/*
 *  fat32_get_current_folder - Copy the current folder state
 *
 *  Parameters:
 *      folder - Destination folder state
 */
void fat32_get_current_folder(struct FAT32Folder* folder);

/*
 *  fat32_set_current_folder_state - Restore the current folder state
 *
 *  Parameters:
 *      folder - Folder state to restore
 */
void fat32_set_current_folder_state(const struct FAT32Folder* folder);

/**
 *  fat32_list_dir - Prints all files in folder to screen
 */
void fat32_list_dir();

/**
 *  fat32_mkdir - Create a new directory on SD card
 *
 *  Parameters:
 *      dirname - Name of the directory to create
 *
 *  Returns:
 *      0 on success, -1 otherwise
 */
int fat32_mkdir(const char* dirname);

/*
 *  fat32_calculate_sector_address - Calculate sector address from cluster and sector
 *
 *  Parameters:
 *      cluster - cluster address
 *      sector  - sector id
 *
 *  Returns:
 *      Returns SD-CARD sector address
 */
unsigned long fat32_calculate_sector_address(unsigned long cluster,
					     unsigned char sector);

/*
 *  fat32_read_sector - Reads sector from SD-CARD
 *
 *  Parameters:
 *      addr - SD-CARD sector address
 */
void fat32_read_sector(unsigned long);

/*
 *  fat32_read_sector_to - Reads sector from SD-CARD into caller buffer
 *
 *  Parameters:
 *      addr - SD-CARD sector address
 *      buf  - Buffer to store sector data
 */
void fat32_read_sector_to(unsigned long, unsigned char*);

/*
 *  fat32_write_sector - Write sector to SD-CARD
 *
 *  Parameters:
 *      addr - SD-CARD sector address
 */
int fat32_write_sector(unsigned long);

/*
 *  fat32_write_sector_from - Write sector to SD-CARD from caller buffer
 *
 *  Parameters:
 *      addr - SD-CARD sector address
 *      buf  - Buffer containing sector data
 */
int fat32_write_sector_from(unsigned long, unsigned char*);

/*
 *  fat32_get_file_entry - Get file from buffer identified by id
 *
 *  Parameters:
 *      id - Identifier
 *
 *  Retrieves pointer to FAT32File* struct identified by ID
 */
const struct FAT32File* fat32_get_file_entry(unsigned int id);

/*
 *  fat32_sort_files - Sort files encountered in folder
 */
void fat32_sort_files();

/*
 *  fat32_file_compare - Compare two FAT32File* file entries
 *
 *  Parameters:
 *      item 1 -  FAT32File pointer to file1
 *      item 2 -  FAT32File pointer to file2
 *
 *  Returns:
 *      -1 if file1 < file2
 *      +1 if file1 > file2
 */
int fat32_file_compare(const void* item1, const void* item2);

/*
 *  fat32_build_linked_list - Build linked list of clusters
 *
 *  Parameters:
 *      nextcluster - starting cluster in the linked list
 */
void fat32_build_linked_list(unsigned long nextcluster);

/*
 *  fat32_grab_cluster_address_from_fileblock - Grab cluster address from sector data
 *
 *  Parameters:
 *      loc - Starting location of raw file entry in SD-CARD buffer
 *
 *  Returns:
 *      Starting cluster address of file
 */
unsigned long fat32_grab_cluster_address_from_fileblock(unsigned char* loc);

/*
 *  fat32_normalize_name_83 - Convert a filename to FAT 8.3 raw format
 *
 *  Parameters:
 *      input - User-facing name
 *      out   - 11-byte FAT 8.3 name buffer
 *
 *  Returns:
 *      0 if the name is valid, -1 otherwise
 */
int fat32_normalize_name_83(const char* input, char out[11]);

/*
 *  fat32_normalize_file_83 - Convert a filename to FAT 8.3 raw format
 *
 *  Parameters:
 *      input - User-facing filename
 *      out   - 11-byte FAT 8.3 name buffer
 *
 *  Returns:
 *      0 if the name is valid, -1 otherwise
 */
int fat32_normalize_file_83(const char* input, char out[11]);

/*
 *  fat32_find_free_cluster - Find the first unused data cluster
 *
 *  Returns:
 *      Cluster number, or 0 if no free cluster was found
 */
unsigned long fat32_find_free_cluster();

/*
 *  fat32_write_fat_entry - Write a FAT entry to all FAT copies
 *
 *  Parameters:
 *      cluster - Cluster whose FAT entry should be written
 *      value   - New low-28-bit FAT value
 *
 *  Returns:
 *      0 on success, -1 otherwise
 */
int fat32_write_fat_entry(unsigned long cluster, unsigned long value);
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

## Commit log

2025-10-19 Initial commit Github Actions
    [TURBOC.CFG, WILDARGS.OBJ]
2025-10-19 Fixing resistor 3d file
    [isa-sdcard.kicad_pcb]
2025-11-03 Adding delays and improving bracket
    [bracket-release-card.stl, isa-sdcard.kicad_pcb, isa-sdcard.kicad_sch]
2025-11-15 Removing delay lines
    [isa-sdcard.kicad_pcb, isa-sdcard.kicad_sch]
2026-10-08 OTTERSD 1.0.0: DOS driver, CI release pipeline and documentation (#6)
    * Incrementing version number
    * Restore DOS CRLF line endings in updated source files (#5)
    * Expanding explanation and polishing settings interface
    * Increasing maximum number of files per folder
    * Fixing files for MSDOS
    * Initial commit SD-CARD write routines
    * Improving commenting and routines
    * Tuning write cycles
    * Improving schematic, improving sd commands and making cross-compilation more convenient
    * Adding JLCPCB numbers
    * Implementing folder creation
    * Refactoring otternav and initial commit copying from HD to SD
    * Refining CPLD card
    * Initial commit DRIVER
    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
    [MicroSD_Socket.STEP, bom.csv, bracket-release-card-text.stl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]
2026-10-16 Prepare Slot-otter v1.1.0 with CPLD revision 1.0 hardware (#7)
    * Working RW driver
    * Consolidation step
    * Conso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
2026-10-17 Improving user feedback for driver interaction
2026-10-18 Correct mounting screws and add rounded Nyloc nuts to card models
2026-10-19 Revising CPLD board and adding OSHWA certification
2026-10-31 Synchronize driver and release metadata for v1.1.5

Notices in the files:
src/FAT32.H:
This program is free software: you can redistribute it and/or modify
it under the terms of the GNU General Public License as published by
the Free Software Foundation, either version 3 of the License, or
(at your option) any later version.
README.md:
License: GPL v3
